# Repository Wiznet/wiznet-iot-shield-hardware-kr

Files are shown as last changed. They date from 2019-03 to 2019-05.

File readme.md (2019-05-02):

# WIZnet IoT Shield Hardware Materials

이 저장소에는 다음 자료들이 포함되어 있습니다.
* WIZnet IoT Shield 및 Cat.M1 인터페이스 보드의 하드웨어 개발 자료
  * `Schematic`, `Gerber`, `BOM` 
  * `Pinout`, `Layout` 
* WIZnet IoT Shield 하드웨어 설정 가이드

## WIZnet IoT Shield Hardware
WIZnet IoT Shield Hardware Materials 저장소에서는 WIZnet IoT Shield의 하드웨어 설정, 보드 개발 자료 및 각종 설계 가이드 문서를 저장하고 공개합니다. 이와 더불어, 제품 활용에 필요한 각종 자료와 프로그램 등도 함께 제공합니다.

**모든 개발 자료는 공개되어 있으며, 자유롭게 활용 하실 수 있습니다.**

## Folder Structure

### /docs
다양한 인터페이스 보드를 지원하는 WIZnet IoT Shield의 모듈 별 점퍼 설정 등 다양한 하드웨어 관련 문서가 위치합니다.
* imgs: 문서에서 활용된 이미지들이 저장된 폴더입니다.

### /hardware
WIZnet IoT Shield 및 인터페이스 보드의 `Schematic`, `Gerber`, `BOM`, `Layout`, `Pinout` 등의 하드웨어 개발 자료입니다. IoT Shield 및 각 Cat.M1 모듈 벤더 별 인터페이스 보드가 각각의 폴더로 나뉘어 있으며, 하드웨어 리비전 별로 관리됩니다.
* WIoT-Shield01_Vxxx: WIZnet IoT Shield 보드의 하드웨어 개발 자료
* WIoT-QC01_Vxxx: 앰투앰넷 BG96(Quectel) 모듈 인터페이스 보드의 하드웨어 개발 자료
* WIoT-WM01_Vxxx: 우리넷 WM-N400MSE 모듈 인터페이스 보드의 하드웨어 개발 자료
* WIoT-AM01_Vxxx: AM텔레콤 AMM5918K 모듈 인터페이스 보드의 하드웨어 개발 자료

### /resources
WIZnet IoT Shield의 활용에 필요한 각종 자료 및 프로그램, 드라이버 등이 위치합니다.

### /settings
Cat.M1 모듈 종류에 따른 WIZnet IoT Shield 하드웨어 설정 정보가 위치합니다.

## Examples of content

### WIZnet IoT Shield Hardware
#### Pinout
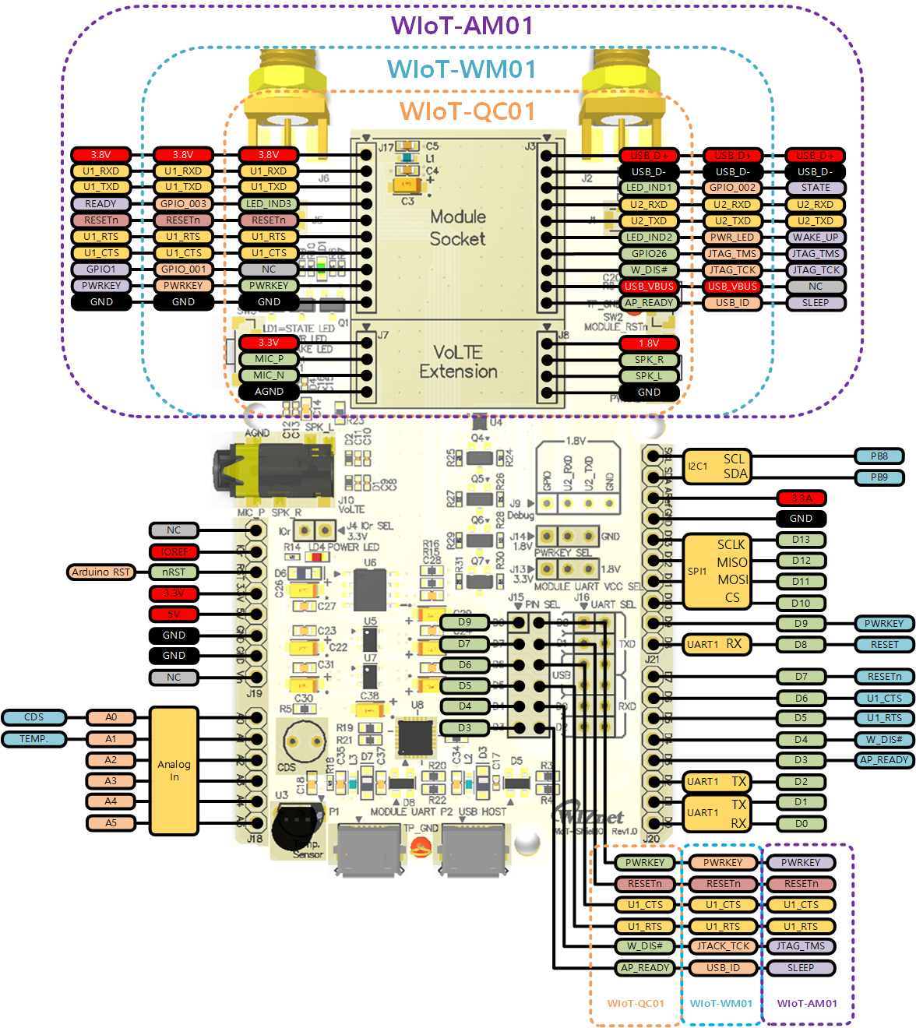
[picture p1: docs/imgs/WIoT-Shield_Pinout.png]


#### Layout
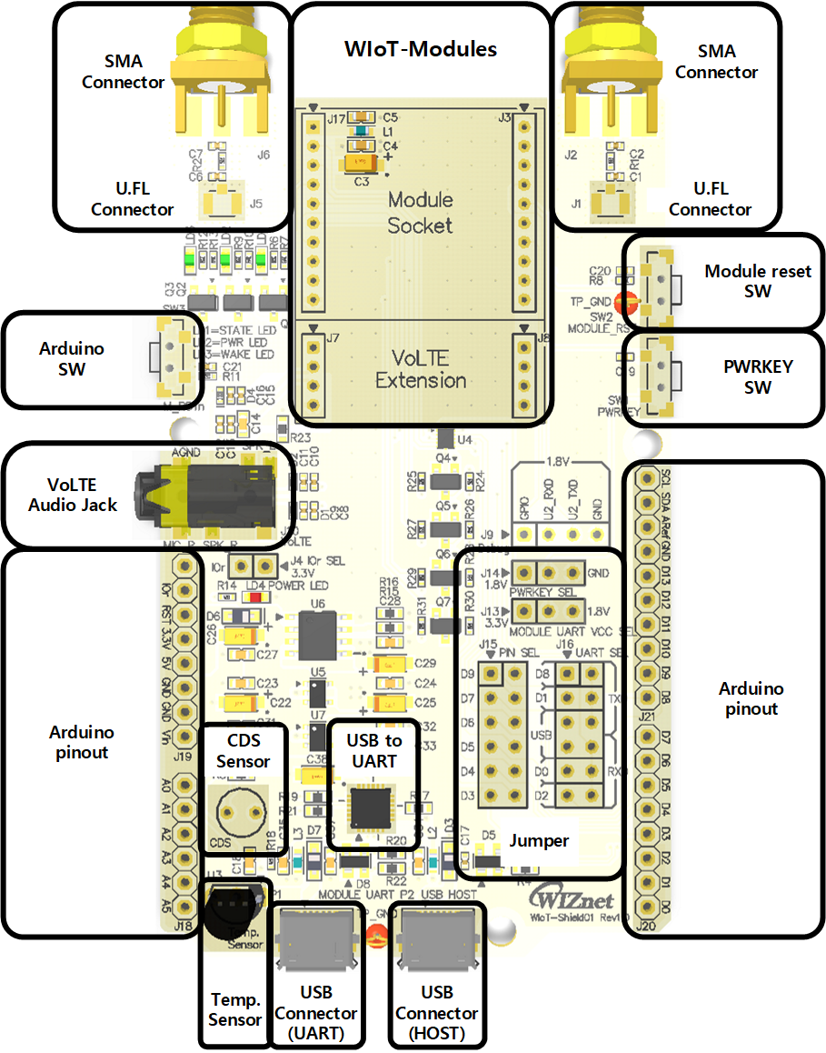
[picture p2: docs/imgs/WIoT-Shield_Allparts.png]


## Other WIZnet IoT Shield Repository
**[wiznet-iot-shield][link-wiznet-iot-shield-kr]** 저장소를 방문하면 다른 플랫폼 보드를 기반으로 동작하는 다양한 예제에 대한 저장소 리스트를 확인 할 수 있습니다.

## Support

[WIZnet Developer Forum](https://forum.wiznet.io/c/korean-forum/oshw/)

**[WIZnet Developer Forum](https://forum.wiznet.io/c/korean-forum/oshw/)** 에서 전세계의 WIZnet 기술 전문가들에게 질문하고 의견을 전달할 수 있습니다.<br>지금 방문하세요!

## License
**WIZnet IoT Shield Hardware Materials** 저장소의 모든 문서와 예제는 [Apache License, Version 2.0](https://www.apache.org/licenses/LICENSE-2.0)으로 배포됩니다.

[forum]: ./docs/imgs/forum.jpg
[link-wiznet-forum]: https://forum.wiznet.io/
[link-wiznet-iot-shield-kr]: https://github.com/Wiznet/wiznet-iot-shield-kr/

[shield-layout]: ./docs/imgs/WIoT-Shield_Allparts.png
[shield-pinout]: ./docs/imgs/WIoT-Shield_Pinout.png

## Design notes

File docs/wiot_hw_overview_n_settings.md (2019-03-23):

# WIZnet IoT Shield Hardware Guide
## 시작하기 전에
### 대상 장치
- WIoT-Shield01 (Base 보드)
- WIoT-QC01 (Socket 타입 모듈)
- WIoT-WM01 (Socket 타입 모듈)
- WIoT-AM01 (Socket 타입 모듈)

## 소개

본 문서에서는 WIoT 제품들의 하드웨어 구성 및 설정에 대한 가이드를 제공합니다.

WIoT 시리즈 보드들은 아두이노, ARM MBED 및 상용 보드 플랫폼을 기반으로 다양한 무선 모듈 응용 개발에 활용 할 수 있는 연결형 보드 및 인터페이스 보드입니다.

다양한 인터페이스 보드가 연결되는 WIoT-Shield Base보드는 두 개의 USB PORT와 CDS, TEMP 센서, VoLTE용 오디오를 지원합니다. Xbee type Socket으로 제작된 Cat.M1 모듈들을 Base보드에 결합하여 사용하도록 구성되어 있으며, 각 모듈의 종류 및 테스트 환경에 따라 WIoT-Shield의  하드웨어 설정이 변경되어야 합니다.

본 가이드는 아래와 같은 순서로 구성되어 있습니다.
 * WIoT 시리즈 하드웨어 Overview
 * WIoT 시리즈 하드웨어 Settings
   * Standard alone mode
   * Arduino/MBED mode (SerialD0,D1)
   * Arduino/MBED mode (SerialD2,D8)

## WIoT 시리즈 모듈

### 1. WIoT-Shield01
WIoT-Shield는 Base보드로서 아두이노, Arm MBED, USB를 통해 5V 전압을 인가받아 동작하며 내부에서 3.8V, 1.8V전압을 변환하여 구동됩니다.

WIoT-Shield는 WIoT 무선 모듈의 기능 동작을 위해 Power key 세팅(HIGH/LOW), UART의 전압 세팅(3.3V/1.8V)등을 제공합니다. 또한 무선 통신을 위한 U.FL, SMA 커넥터와 VoLTE 기능이 구현되어 있습니다. 프로토타입 구현에 활용 할 수 있는 CDS(조도센서), Temp.(온도센서)가 내장되어 있어 아두이노 및 Arm MBED 플랫폼 보드와 결합하여 사용 가능합니다.

#### Features
* Arduino compatible pinout
* 3종 LTE CAT.M1 모듈 사용(Quectel,AMTelecom,Woori-net)
* Power key 세팅(HIGH/LOW)
* UART 전압 세팅(3.3V/1.8V)
* VoLTE Audio JACK 구현
* U.FL / SMA 안테나 커넥터 내장
* CDS, TEMP 센서 내장
* 모듈의 부가 기능 사용을 위해 Jumper 기능 내장
* Standard alone 동작을 위한 USB 커넥터 내장
* RNDIS기능을 위한 USB 커넥터 내장





### 2. WIoT-QC01
WIoT-QC01보드는 앰투앰넷 BG96(Quectel) 모듈로 개발된 LTE Cat.M1 무선 모듈입니다.
무선 통신 시스템과 VoLTE기능을 사용할 수 있으며 Micro-SIM과 e-SIM중 한 가지를 제공합니다.

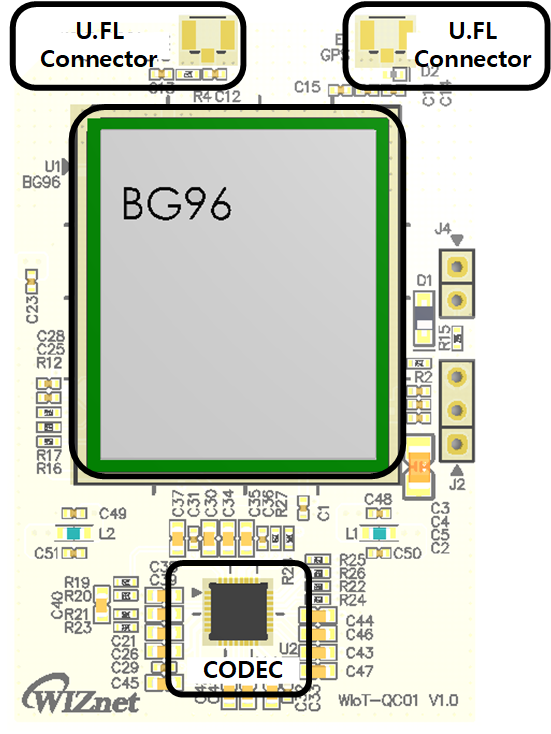
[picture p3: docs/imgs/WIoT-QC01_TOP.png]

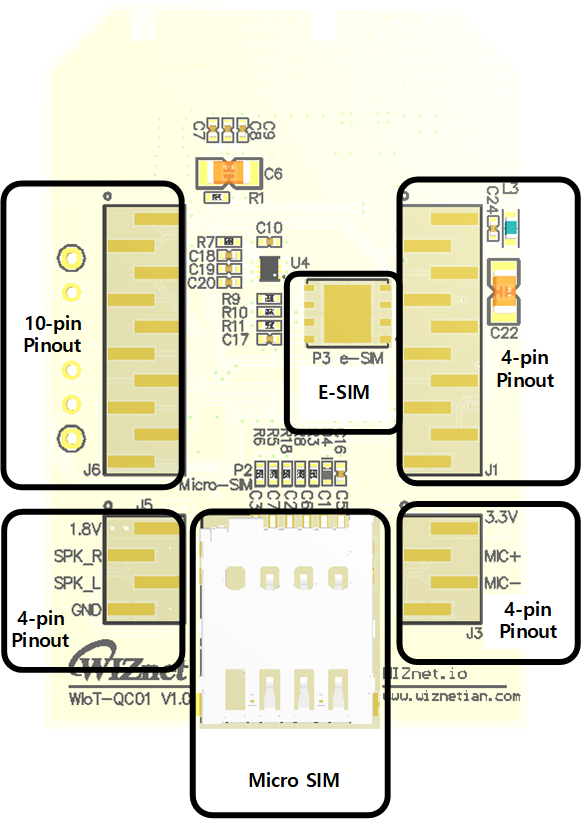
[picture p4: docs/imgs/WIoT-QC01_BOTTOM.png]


### 3. WIoT-WM01
WIoT-WM01보드는 우리넷의 WM-N400MSE을 사용하기 위한 인터페이스 보드로서 PCIe 인터페이스와 JTAG기능을 제공합니다.
Nano-SIM과 e-SIM중 한 가지를 사용할 수 있습니다.

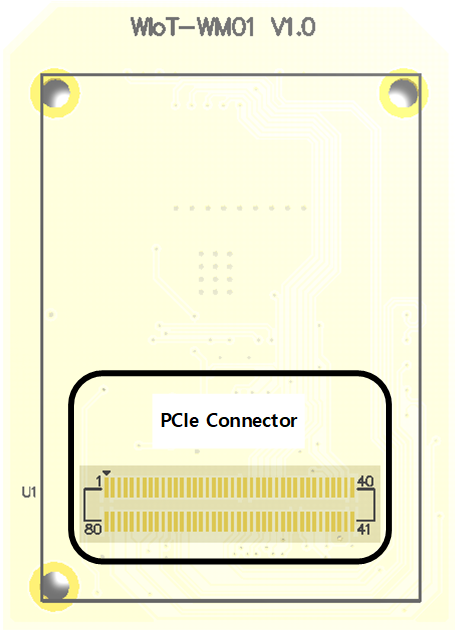
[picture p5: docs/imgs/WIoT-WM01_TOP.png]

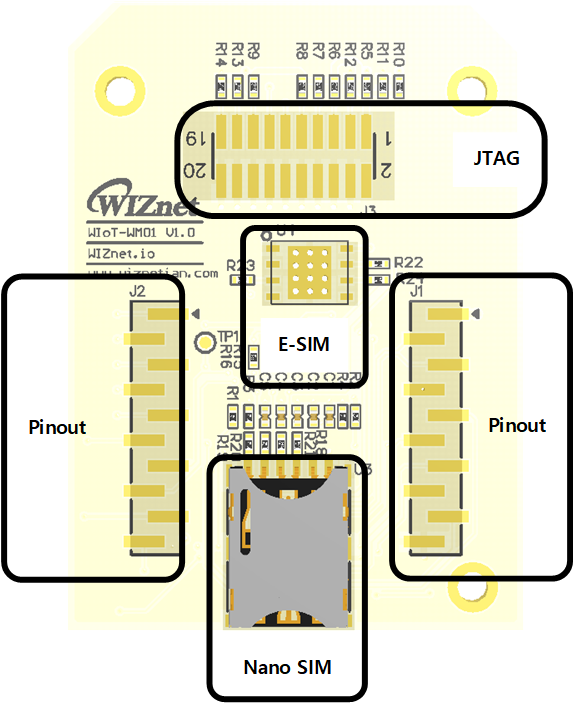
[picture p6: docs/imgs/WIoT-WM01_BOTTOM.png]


### 4. WIoT-AM01
WIoT-AM01보드는 AMTELCOM의 AMM592을 사용하기 위한 인터페이스 보드로서 PCIe 인터페이스와 JTAG기능을 제공합니다.
Micro-SIM과 e-SIM중 한 가지를 사용할 수 있습니다.

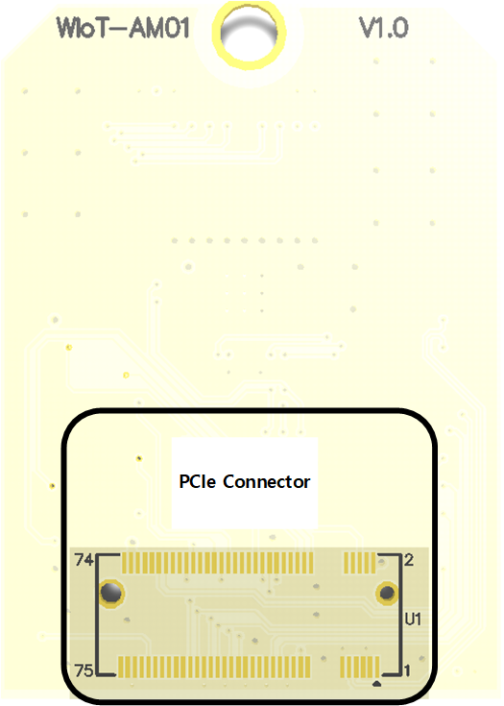
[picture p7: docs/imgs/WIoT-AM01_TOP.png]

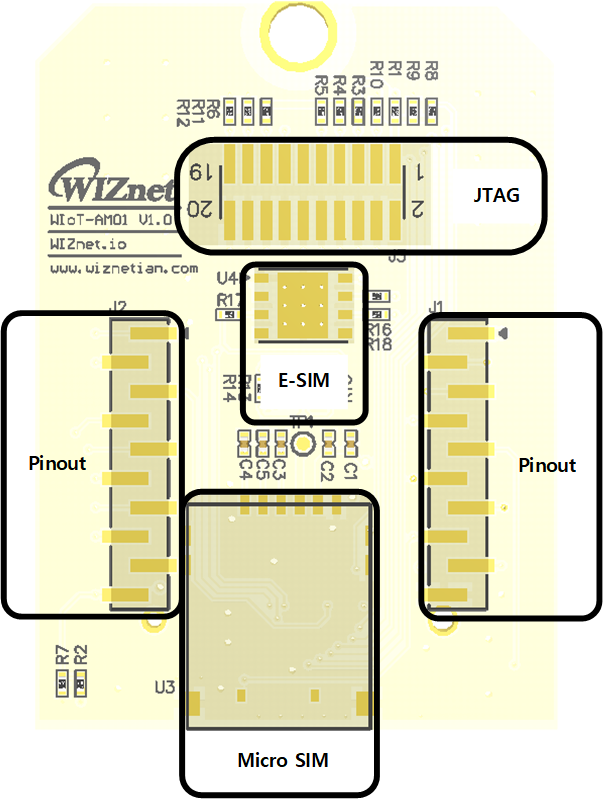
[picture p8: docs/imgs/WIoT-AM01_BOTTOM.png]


## 하드웨어 설정

### 1. WIoT 보드 기본 설정
WIoT-Shield의 기본적인 설정방법은 다음과 같습니다.

* WIoT-QC01 하드웨어 설정
  * Standard alone mode
  * Arduino / MBED mode (Serial D0,D1)
  * Arduino / MBED mode (Serial D2,D8)
* WIoT-WM01 하드웨어 설정
  * Standard alone mode
  * Arduino / MBED mode (Serial D0,D1)
  * Arduino / MBED mode (Serial D2,D8)
* WIoT-AM01 하드웨어 설정
  * Standard alone mode
  * Arduino / MBED mode (Serial D0,D1)
  * Arduino / MBED mode (Serial D2,D8)

### 2. WIoT-QC01 하드웨어 설정
* Standalone mode
  * 해당 모드는 아두이노 / MBED 등 다른 MCU기기를 결합하지 않고 WIoT-QC01를 테스트할 수 있습니다.

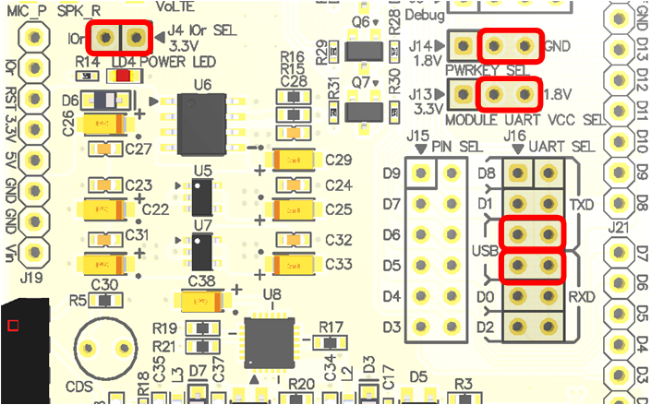
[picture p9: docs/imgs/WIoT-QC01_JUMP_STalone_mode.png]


* Arduino / MBED mode (Serial D0,D1)
  * 해당 모드는 아두이노 / MBED 등 MCU 보드의 `D0` `D1` 핀에 할당된 UART를 Cat.M1 모듈과 연결합니다.

> **Notice) 아두이노에서 코드 컴파일 및 업로드는 WIoT-Shield의 UART Jumper 제거 후 수행해야 합니다.**

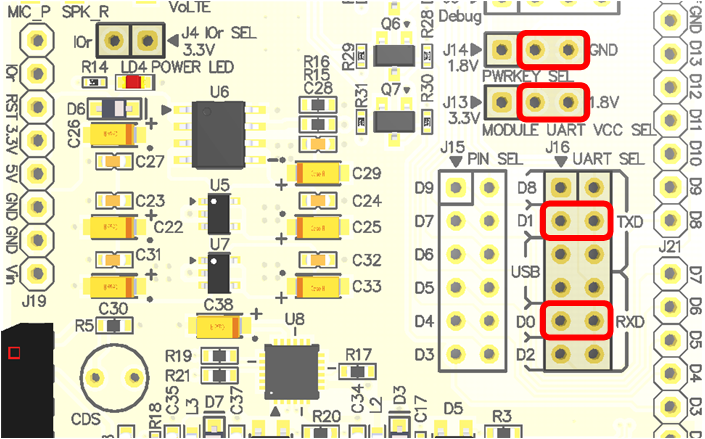
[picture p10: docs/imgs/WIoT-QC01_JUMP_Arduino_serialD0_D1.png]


* Arduino / MBED mode (Serial D2,D8)
  * 해당 모드는 아두이노 / MBED 등 MCU 보드의 `D2` `D8` 핀에 할당된 UART를 Cat.M1 모듈과 연결합니다.

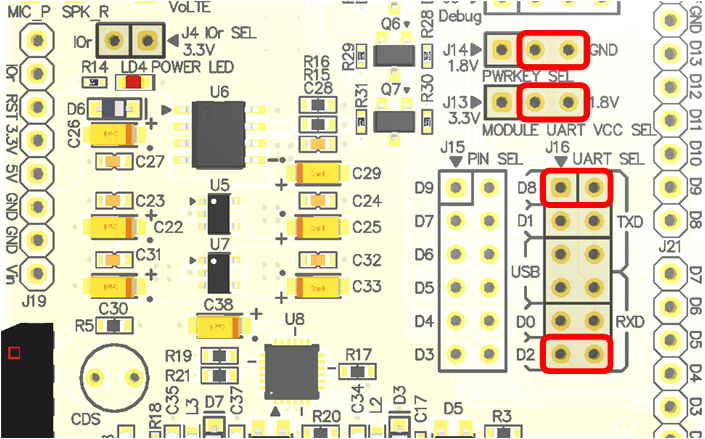
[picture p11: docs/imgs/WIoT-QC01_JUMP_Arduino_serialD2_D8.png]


### 3. WIoT-WM01 하드웨어 설정
* Standalone mode
  * 해당 모드는 아두이노 / MBED 등 다른 MCU기기를 결합하지 않고 WIoT-WM01를 테스트할 수 있습니다.

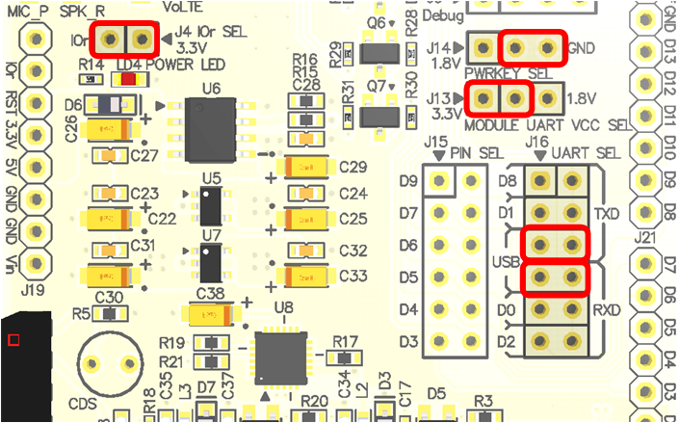
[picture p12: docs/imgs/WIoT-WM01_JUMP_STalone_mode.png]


* Arduino / MBED mode (Serial D0,D1)
  * 해당 모드는 아두이노 / MBED 등 MCU 보드의 `D0` `D1` 핀에 할당된 UART를 Cat.M1 모듈과 연결합니다.

> **Notice) 아두이노에서 코드 컴파일 및 업로드는 WIoT-Shield의 UART Jumper 제거 후 수행해야 합니다.**

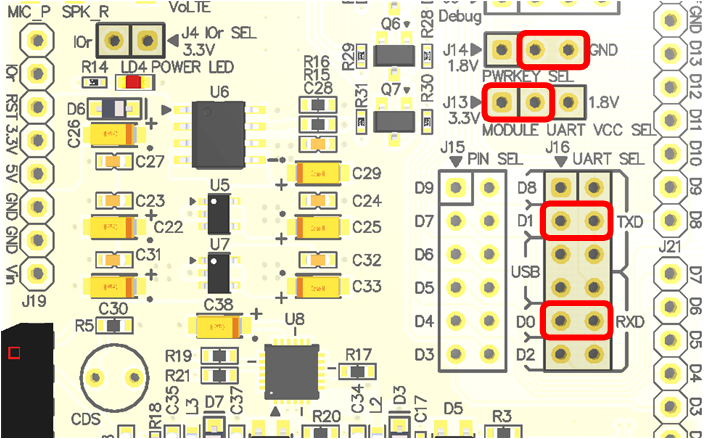
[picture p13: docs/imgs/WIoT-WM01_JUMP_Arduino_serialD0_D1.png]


* Arduino / MBED mode (Serial D2,D8)
  * 해당 모드는 아두이노 / MBED 등 MCU 보드의 `D2` `D8` 핀에 할당된 UART를 Cat.M1 모듈과 연결합니다.

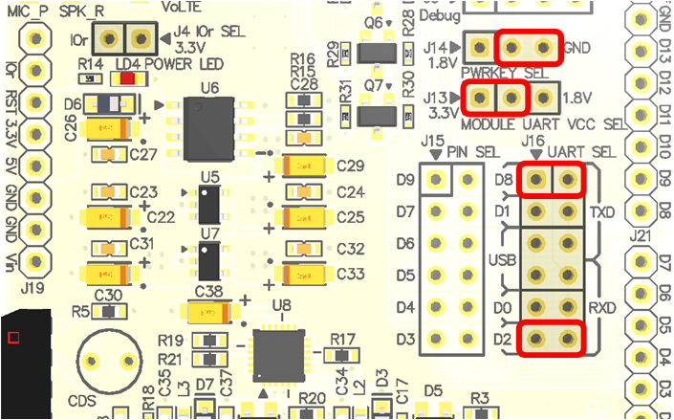
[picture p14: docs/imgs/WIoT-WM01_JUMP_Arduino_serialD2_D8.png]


### 4. WIoT-AM01 하드웨어 설정
* Standalone mode
  * 해당 모드는 아두이노/MBED 등 다른 MCU기기를 결합하지 않고 WIoT-AM01를 테스트할 수 있습니다.

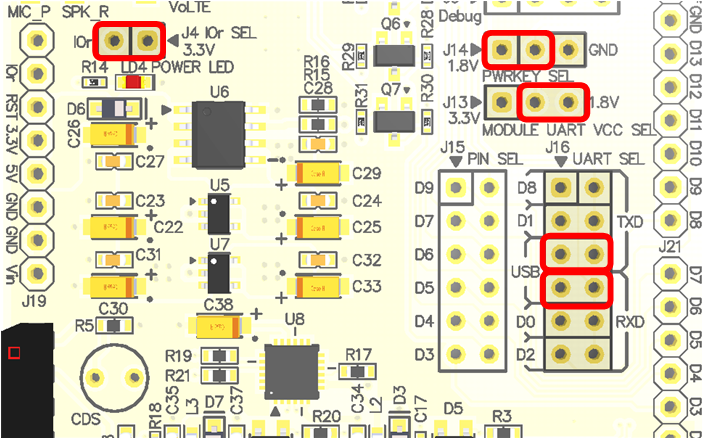
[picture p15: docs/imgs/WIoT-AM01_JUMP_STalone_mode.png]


* Arduino / MBED mode (Serial D0,D1)
  * 해당 모드는 아두이노 / MBED 등 MCU 보드의 `D0` `D1` 핀에 할당된 UART를 Cat.M1 모듈과 연결합니다.

> **Notice) 아두이노에서 코드 컴파일 및 업로드는 WIoT-Shield의 UART Jumper 제거 후 수행해야 합니다.**

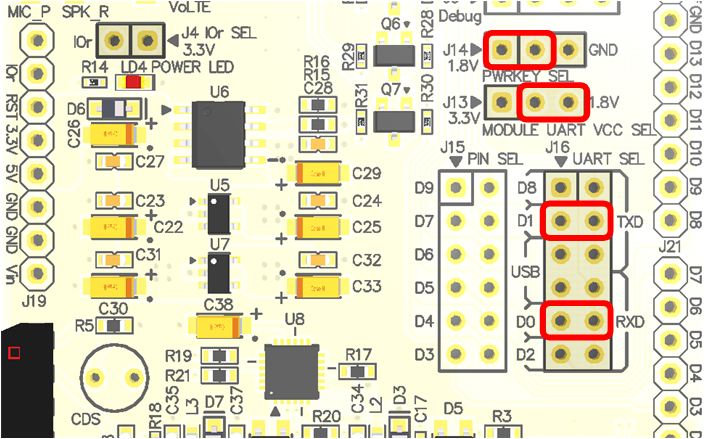
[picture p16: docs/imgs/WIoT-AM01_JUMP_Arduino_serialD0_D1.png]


* Arduino / MBED mode (Serial D2,D8)
  * 해당 모드는 아두이노 / MBED 등 MCU 보드의 `D2` `D8` 핀에 할당된 UART를 Cat.M1 모듈과 연결합니다.

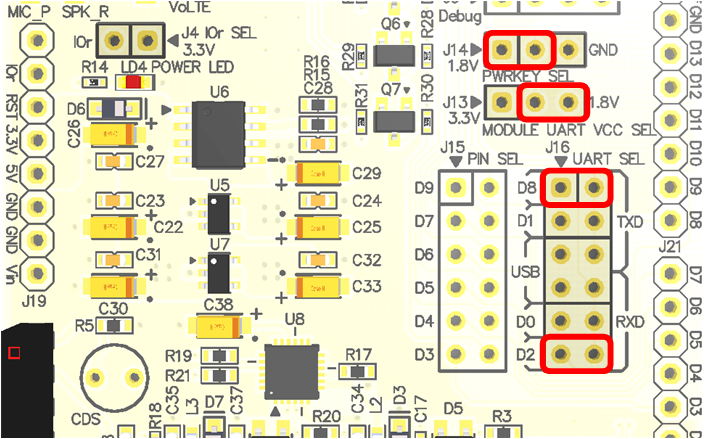
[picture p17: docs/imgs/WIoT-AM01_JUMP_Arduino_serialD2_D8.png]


[1]: ./imgs/WIoT_allparts.png
[2]: ./imgs/WIoT_series_Pinout.png
[3]: ./imgs/WIoT-AM01_TOP.png
[4]: ./imgs/WIoT-AM01_BOTTOM.png
[5]: ./imgs/WIoT-AM01_Pinout.png
[6]: ./imgs/WIoT-AM01_JUMP_STalone_mode.png
[7]: ./imgs/WIoT-AM01_JUMP_Arduino_serialD0_D1.png
[8]: ./imgs/WIoT-AM01_JUMP_Arduino_serialD2_D8.png
[9]: ./imgs/WIoT-QC01_TOP.png
[10]: ./imgs/WIoT-QC01_BOTTOM.png
[11]: ./imgs/WIoT-QC01_Pinout.png
[12]: ./imgs/WIoT-QC01_JUMP_STalone_mode.png
[13]: ./imgs/WIoT-QC01_JUMP_Arduino_serialD0_D1.png
[14]: ./imgs/WIoT-QC01_JUMP_Arduino_serialD2_D8.png
[15]: ./imgs/WIoT-WM01_TOP.png
[16]: ./imgs/WIoT-WM01_BOTTOM.png
[17]: ./imgs/WIoT-WM01_Pinout.png
[18]: ./imgs/WIoT-WM01_JUMP_STalone_mode.png
[19]: ./imgs/WIoT-WM01_JUMP_Arduino_serialD0_D1.png
[20]: ./imgs/WIoT-WM01_JUMP_Arduino_serialD2_D8.png

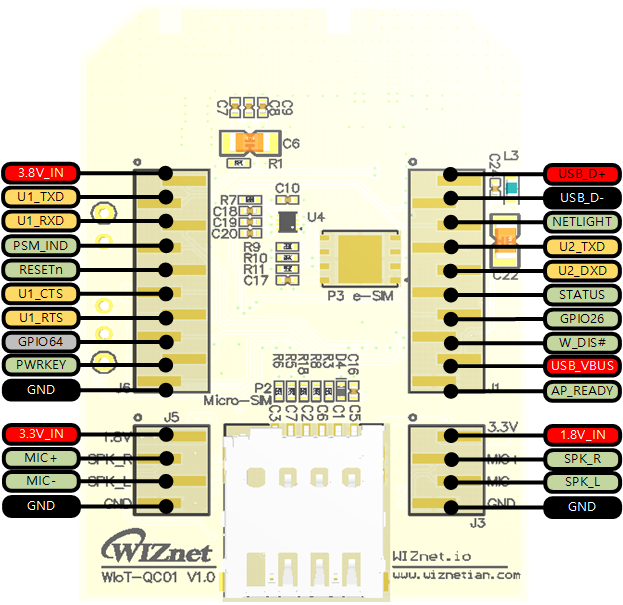
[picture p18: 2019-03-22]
docs/imgs/WIoT-QC01_Pinout.png

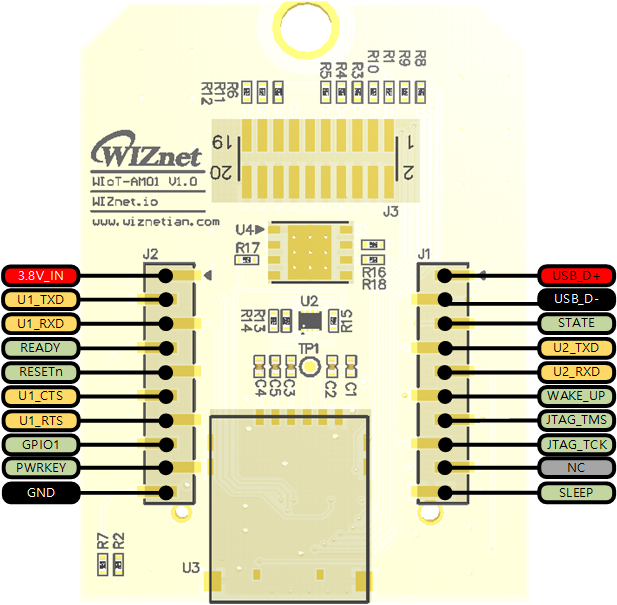
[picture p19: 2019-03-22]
docs/imgs/WIoT-AM01_Pinout.png

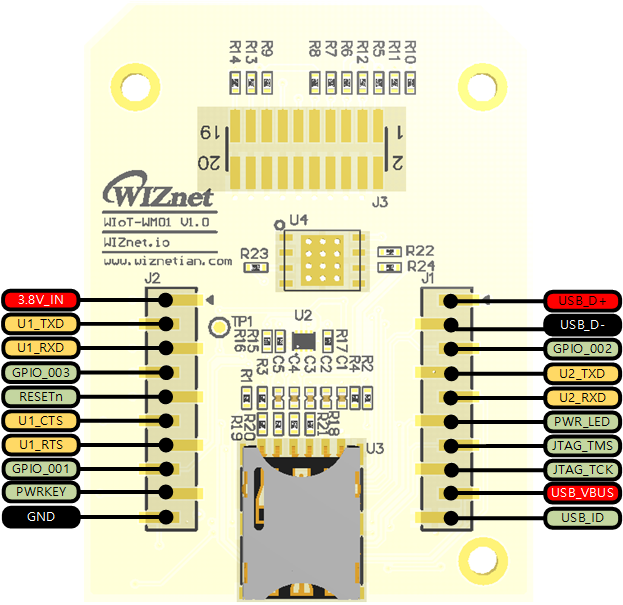
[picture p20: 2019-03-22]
docs/imgs/WIoT-WM01_Pinout.png

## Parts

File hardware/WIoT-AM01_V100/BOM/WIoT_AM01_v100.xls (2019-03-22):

WIoT-AM01 V1.0 Partlist
Item | Q.ty | Reference | Part | Tech. Characteristics | Package
1 | 1 | C1 | 1uF | 50V-5% Ceramic | CASE 0402
2 | 4 | C2,C3,C4,C5 | 33pF | 50V-5% Ceramic | CASE 0402
3 | 2 | J1,J2 | 2.00mm Pin haeder SMD 1x10 | 2.00mm Pin haeder 1x10, SMD Male | SMD
4 | 3 | R16,R17,R18 | 0R | 1/10W-5% SMD | CASE 0402
6 | 1 | U1 | 24-6411-067-101-894B | PCIe interface connector (Kyocera) | SMD
7 | 1 | U2 | TPD3F303DQDR | ESD Protection SIM | PWSON08(0.4/1.45X1.8)
8 | 1 | U3 | MOLEX-SD-78646-001 | Micro SIM SMT 1.45mm Push/Pull (Molex) | SMD
9 | 1 | J3 | 1.27mm 2x10 Pin Header SMD | Not Mount | SMD
10 | 1 | J4 | 2.54mm Pin haeder 1x2 | Not Mount | DIP
11 | 1 | U4 | e-SIM | Not Mount | SMD
12 | 4 | R1,R13,R14,R15 | 0R | Not Mount | CASE 0402
13 | 10 | R2,R3,R4,R5,R6,R7,R8,R9,R11,R12 | 10k | Not Mount | CASE 0402
14 | 1 | R10 | 47k | Not Mount | CASE 0402
15 | 1 |  | PCB | 4-Layer 50mm x 36mm

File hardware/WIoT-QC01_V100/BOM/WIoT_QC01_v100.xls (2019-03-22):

WIoT-QC01 V1.0 Partlist
Item | Q.ty | Reference | Part | Tech. Characteristics | Package
1 | 17 | C1,C3,C7,C10,C16,C23,C24,C25,C28,C29,C31,C33,C36,C48,C49,C50,C51 | 0.1uF | 50V-5% Ceramic | CASE 0402
2 | 2 | C43,C44 | 1uF | 25V-5% Ceramic | CASE 0603
3 | 8 | C34,C35,C38,C39,C41,C42,C46,C47 | 2.2uF | 25V-5% Ceramic | CASE 0603
4 | 6 | C21,C26,C30,C32,C37,C45 | 4.7uF | 25V-5% Ceramic | CASE 0603
5 | 1 | C22 | 4.7uF/16V | Tantal CAP, A Size, 4.7uF/16V, +/-20% | EIA/IECQ 3216
6 | 1 | C40 | 10uF | 25V-5% Ceramic | CASE 0603
7 | 2 | C2,C6 | 10uF/16V | Tantal CAP, A Size, 10uF/16V, +/-20% | EIA/IECQ 3216
8 | 2 | C5,C9 | 10pF | 25V-5% Ceramic | CASE 0402
9 | 5 | C4,C8,C18,C19,C20 | 33pF | 25V-5% Ceramic | CASE 0402
10 | 1 | C11 | 100pF | 25V-5% Ceramic | CASE 0402
11 | 2 | J1,J6 | 2.00mm Pin haeder SMD 1x10 | 2.00mm Pin haeder 1x10, SMD Male | SMD
12 | 2 | J3,J5 | 2.00mm Pin haeder SMD 1x4 | 2.00mm Pin haeder 1x4, SMD Male | SMD
13 | 1 | P2 | MOLEX-SD-78646-001 | Micro SIM SMT 1.45mm Push/Pull (Molex) | SMD
14 | 2 | E1,E2 | 20279-001E-03 | U.FL Connector | SMD
15 | 2 | L1,L2,L3 | HH-1M1608-121JT | Bead for Power Line, 120[ohm] | CASE 0603
16 |  | D1 | PZ3D4V2H | Zener 5.1V | SOD-323
17 | 1 | D2 | LXES15AAA1-133 | Bi-directional TVS diode | D0402
18 | 1 | D4 | ESD9X5.0ST5G | Uni-directional TVS diode | SOD-923(1-C,2-A)
19 | 11 | R1,R2,R4,R5,R6,R8,R18,R22,R24,R25,R26 | 0R | 1/10W-5% SMD | CASE 0402
20 | 2 | R19,R23 | 1k | 1/10W-5% SMD | CASE 0402
21 | 2 | R20,R21 | 1.5k | 1/10W-5% SMD | CASE 0402
22 | 6 | R12,R15,R16,R17,R27,R28 | 4.7K | 1/10W-5% SMD | CASE 0402
23 | 1 | R7 | 15k | 1/10W-5% SMD | CASE 0402
24 | 1 | R3 | 51k | 1/10W-5% SMD | CASE 0402
25 | 1 | U1 | BG96 | Quectel, BG96, LTE CAT M1 module, | BG-96
26 | 1 | U2 | ALC5616 | AUDIO CODEC with QUECTEL VOLTE (Realtek) | QFN32(0.4/4.0)
27 | 1 | U4 | TPD3F303DQDR | ESD Protection SIM | PWSON08(0.4/1.45X1.8)
28 | 5 | C12,C13,C14,C15,C17 | 0.1uF | Not Mount | CASE 0402
29 | 1 | J2 | 2.54mm Pin haeder 1x3 | Not Mount | DIP
30 | 1 | J4 | 2.54mm Pin haeder 1x2 | Not Mount | DIP
31 | 1 | P3 | e-SIM | Not Mount | SMD
32 | 3 | R9,R10,R11 | 0R | Not Mount | CASE 0402
33 | 1 |  | PCB | 4-Layer 54mm x 36mm

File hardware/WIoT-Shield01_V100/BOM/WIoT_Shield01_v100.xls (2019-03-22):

WIoT-Shield01 V1.0 Partlist
Item | Q.ty | Reference | Part | Tech. Characteristics | Package
1 | 4 | C17,C19,C20,C21 | 0.1uF | 50V-5% Ceramic | CASE 0402
2 | 12 | C4,C5,C18,C23,C24,C27,C28,C31,C32,C34,C35,C37 | 0.1uF | 50V-5% Ceramic | CASE 0603
3 | 1 | C14 | 4.7uF | 50V-5% Ceramic | CASE 0603
4 | 6 | C3,C22,C25,C30,C33,C38 | 4.7uF/16V | Tantal CAP, A Size, 4.7uF/16V, +/-20% | EIA/IECQ 3216
5 | 2 | C26,C29 | 10uF/16V | Tantal CAP, A Size, 10uF/16V, +/-20% | EIA/IECQ 3216
6 | 4 | C8,C10,C12,C15 | 10pF | 25V-5% Ceramic | CASE 0402
7 | 4 | C9,C11,C13,C16 | 33pF | 25V-5% Ceramic | CASE 0402
8 | 2 | J1,J5 | 20279-001E-03 | U.FL CONNECTOR | SMD
9 | 2 | J2,J6 | SMA_Female SMA-4-4R 1.6T | SMA_Female | SMD
10 | 2 | J3,J17 | 2.00mm 1x10 Pin Header Socket | 2.00mm 1x10 Pin Header Socket DIP | DIP
11 | 1 | J4 | 2.54mm 1x2 Pin Header DIP | 2.54mm 1x2 Pin Header DIP | DIP
12 | 2 | J7, J8 | 2.00mm 1x4 Pin Header DIP | 2.00mm 1x4 Pin Header Socket DIP | DIP
13 | 2 | J13,J14 | 2.54mm 1x3 Pin Header DIP | 2.54mm 1x3 Pin Header DIP | DIP
14 | 2 | J15,J16 | 2.54mm 2x6 Pin Header DIP | 2.54mm 2x6 Pin Header DIP | DIP
15 | 1 | J18 | 2702747 | ARDUINO 2.54mm 1x6 Pin Header Socket DIP | DIP
16 | 2 | J19,J20 | 2702747 | ARDUINO 2.54mm 1x8 Pin Header Socket DIP | DIP
17 | 1 | J21 | 2702747 | ARDUINO 2.54mm 1x10 Pin Header Socket DIP | DIP
18 | 2 | P1,P2 | 47346-0001 | USB-MOLEX-47346 | MICRO USB B Type
19 | 1 | J10 | gec-3896D | Phonejack 6pin | SMD
20 | 3 | SW1,SW2,SW3 | NW3-A06-B5 | Angle TACT SW, SMD | SMD
21 | 3 | L1,L2,L3 | HH-1M1608-121JT | Bead for Power Line, 120[ohm] | CASE 0603
22 | 2 | D1,D2 | ESD9B5.0ST5G | Bi-directional TVS diode | SOD-882(TVS)
23 | 3 | D3,D6,D7 | BAT60A | Silicon Schottky Diode | SOD-323(1-C,2-A)
24 | 1 | D4 | ESD9X5.0ST5G | Uni-directional TVS diode | SOD-923(1-C,2-A)
25 | 2 | D5, D8 | PRTR5V0U2X | Ultra low capacitance double rail-to-rail ESD protection diode | SOT-143
26 | 4 | LD1,LD2,LD3 | Green LED | CHIP-LED, Red | CASE 0603
27 | 1 | LD4 | Red LED | CHIP-LED, Red | CASE 0603
28 | 3 | R1,R2,R18 | 0R | 1/10W-5% SMD | CASE 0402
29 | 3 | R19,R21,R23 | 0R | 1/10W-5% SMD | CASE 0603
30 | 4 | 'R3,R4,R20,R22 | 33R | 1/10W-5% SMD | CASE 0603
31 | 7 | R6,R7,R9,R10,R12,R13,R14 | 1k | 1/10W-5% SMD | CASE 0402
32 | 8 | R24,R25,R26,R27,R28,R29,R30,R31 | 4.7K | 1/10W-5% SMD | CASE 0402
33 | 1 | R17 | 4.7k | 1/10W-5% SMD | CASE 0603
34 | 1 | R5 | 10k | 1/10W-1% SMD | CASE 0603
35 | 1 | R16 | 30.1k | 1/10W-5% SMD | CASE 0603
36 | 1 | R15 | 200k | 1/10W-5% SMD | CASE 0603
37 | 1 | CDS | GL5537 | 10k, Photoresistor | DIP
38 | 1 | U3 | LM35 | Temperature Sensor | TO-92
39 | 1 | U4 | NLSX5014MUTAG | Level-Shifter | UQFN12(0.4/1.7X2)
40 | 1 | U5 | AP7365-33WG-7 | 3.3V 600mA Regulator/SOT25(Fixed Output) | SOT-25
41 | 1 | U6 | TPS7A7002DDAR | TPS7A7002DDAR | SO-08-EP
42 | 1 | U7 | AP7365-18WG-7 | 3.3V 600mA Regulator/SOT25(Fixed Output) | SOT-25
43 | 1 | U8 | CP2104-GM | USB to UART Bridge, SiliconLabs | QFN24(0.5/4X4)
44 | 3 | Q1,Q2,Q3 | Q-MMBT4401 | NPN General-Purpose Amplifier | SOT-23-3L
45 | 4 | Q4,Q5,Q6,Q7 | Q-2N7002 | N-Channel 60-V (D-S) MOSFET | SOT-23-3L
46 | 4 | C1,C2,C6,C7 | 0.1uF | Not Mount | CASE 0402
47 | 1 | J9 | 2.54mm Pin haeder 1x4 | Not Mount | DIP
48 | 2 | R8,R11 | 0R | Not Mount | CASE0402
49 | 1 |  | PCB | 4-Layer 90mm x 53.315mm

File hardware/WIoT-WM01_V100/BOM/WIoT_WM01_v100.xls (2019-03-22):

WIoT-WM01 V1.0 Partlist
Item | Q.ty | Reference | Part | Tech. Characteristics | Package
1 | 2 | C1 | 1uF | 50V-5% Ceramic | CASE 0402
2 | 5 | C2,C3,C4,C5 | 33pF | 50V-5% Ceramic | CASE 0402
3 | 2 | J1,J2 | 2.00mm Pin haeder SMD 1x10 | 2.00mm Pin haeder 1x10, SMD Male | SMD
5 | 6 | R15,R16,R17,R19,R20,R21 | 0R | 1/10W-5% SMD | CASE 0402
6 | 1 | U1 | AXK6F80347YG | PCIe interface connector (Panasonic Industrial Devices) | SMD
7 | 1 | U3 | 693-043-020-611 | Nano SIM SMT 1.2mm Push/Pull (Wurth Electronics) | 693-043-020-611
8 | 5 | U2 | TPD3F303DQDR | Not Mount | PWSON08(0.4/1.45X1.8)
9 |  | U4 | e-SIM | Not Mount | SMD
10 | 1 | J3 | 1.27mm 2x10 Pin Header SMD | Not Mount | SMD
11 | 4 | R18,R22,R23,R24 | 0R | Not Mount | CASE 0402
12 | 13 | R1,R2,R3,R4,R5,R6,R7,R8,R9,R10,R11,R13,R14 | 10k | Not Mount | CASE 0402
13 | 1 | R12 | 47K | Not Mount | CASE 0402
14 | 1 |  | PCB | 4-Layer 50mm x 36mm

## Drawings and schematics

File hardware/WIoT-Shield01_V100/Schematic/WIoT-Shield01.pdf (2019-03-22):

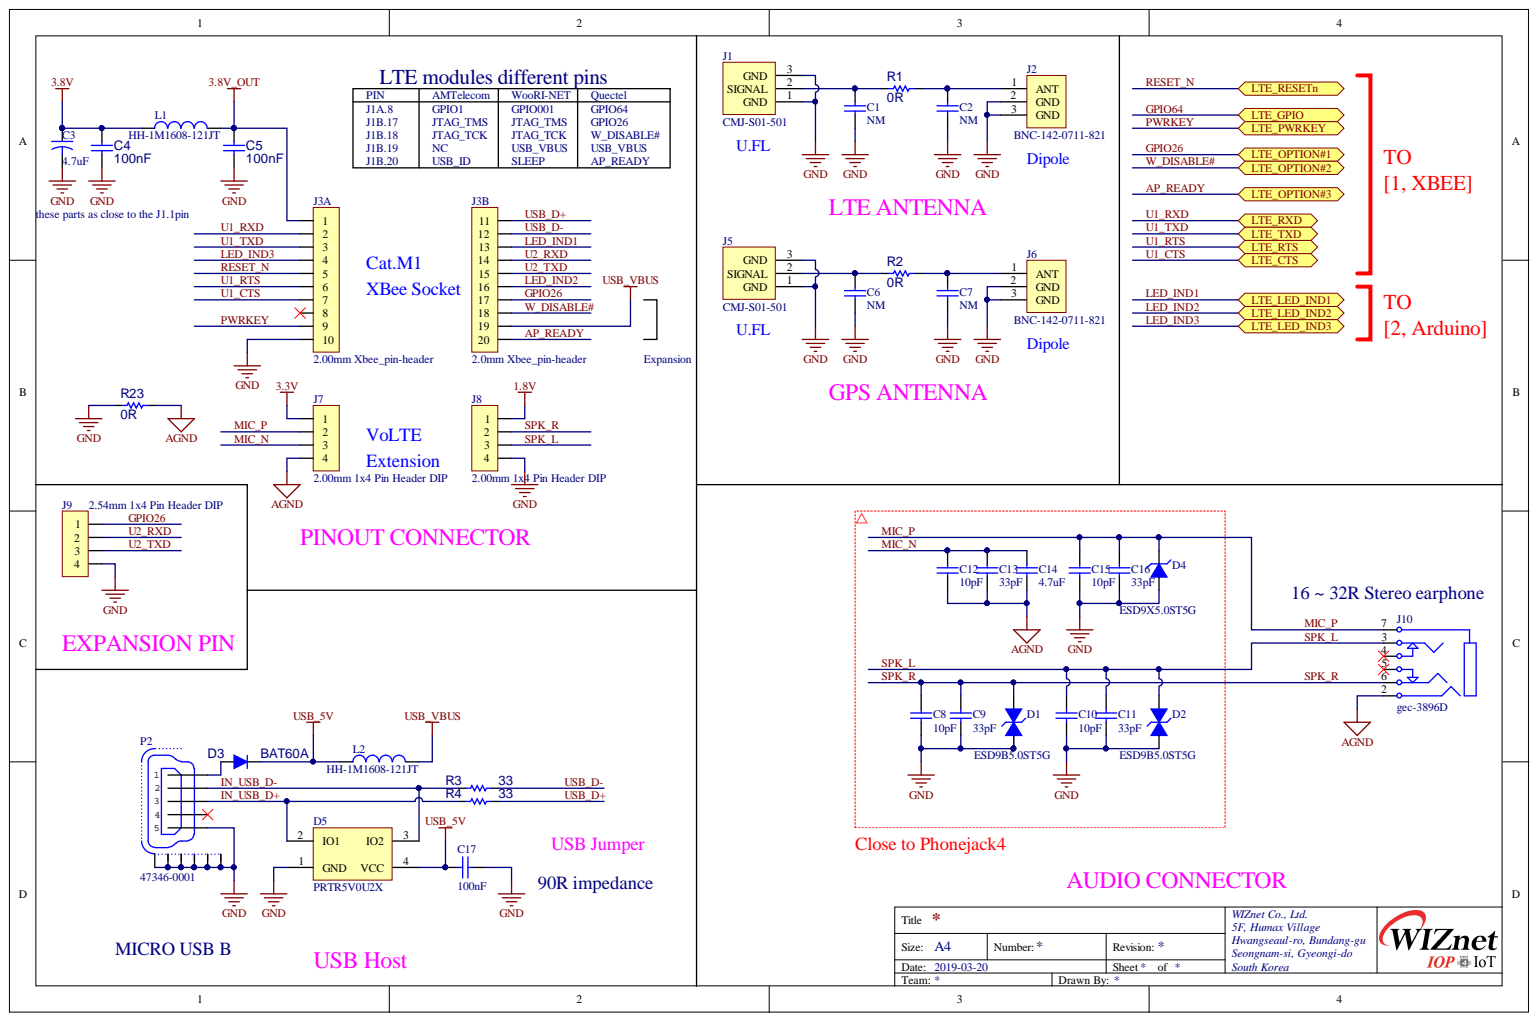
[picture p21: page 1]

LTE modules different pins

these parts as close to the J1.1pin

GND 2

W_DISABLE#

* Title | WIZnet Co., Ltd. 5F, Humax Village Hwangseaul-ro, Bundang-gu Seongnam-si, Gyeongi-do South Korea

A4 Size: | * Number: | * Revision:

Date: 2019-03-20 | | Sheet * of *
Team: * | Drawn By: *

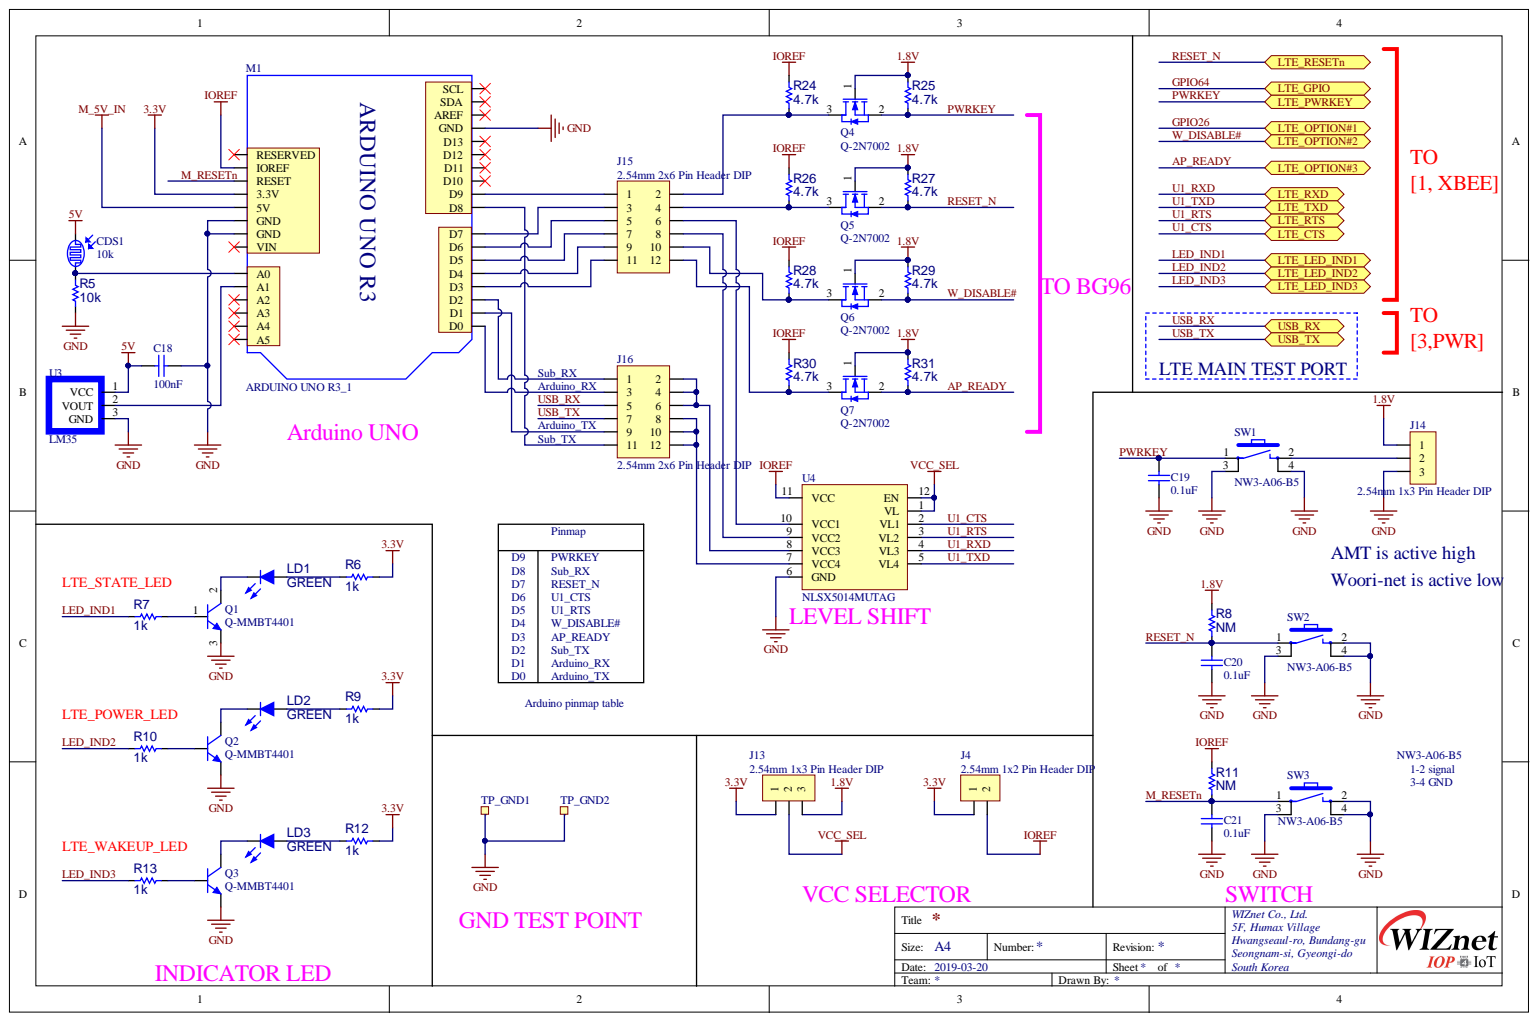
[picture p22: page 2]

GND AREF SDA SCL

RESERVED IOREF RESET 3.3V 5VGND GND
RESETn GND

* Titl e | WIZn et Co. , Ltd. 5 F, Humax Vi l l a g e Hwan gseau l-r o , Bunda ng-g u S e ong nam-s i , Gy eon g i-do Sou th Kore a

A4 * S ize : | * Drawn Nu mb er: | * R e vi s ion :

Da t e : | | S h e e t o f
Te a m : | By:

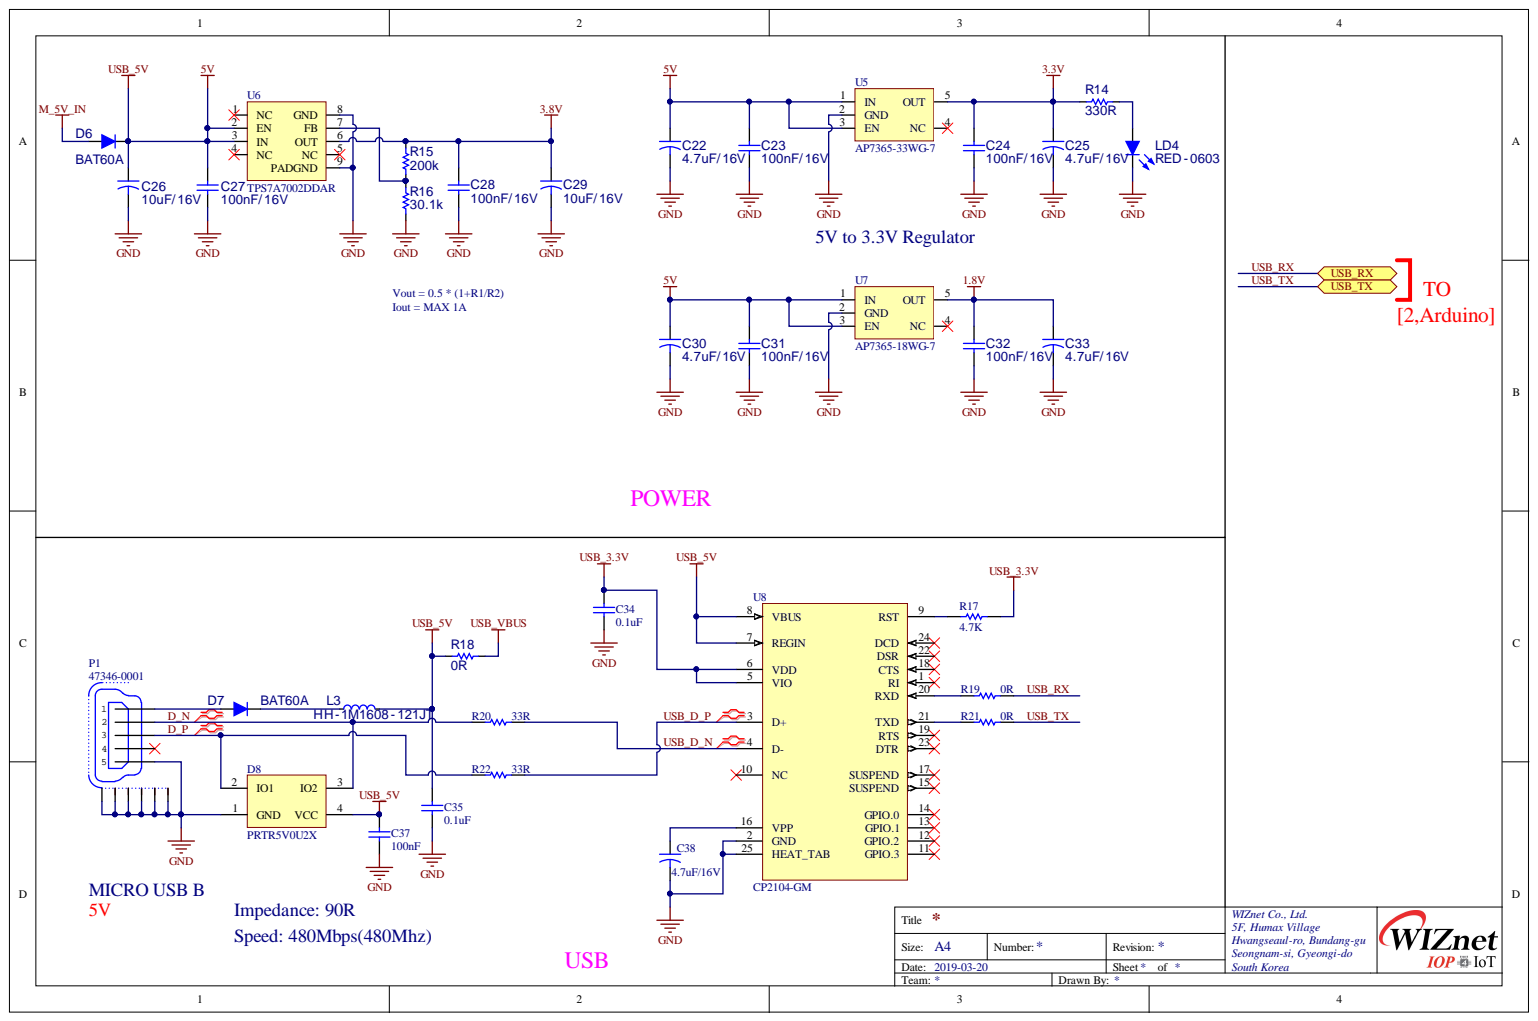
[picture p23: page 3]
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

A4 Size: | * Number: | * Revision:

Date: | | Sheet of *
Team: * | Drawn By: *

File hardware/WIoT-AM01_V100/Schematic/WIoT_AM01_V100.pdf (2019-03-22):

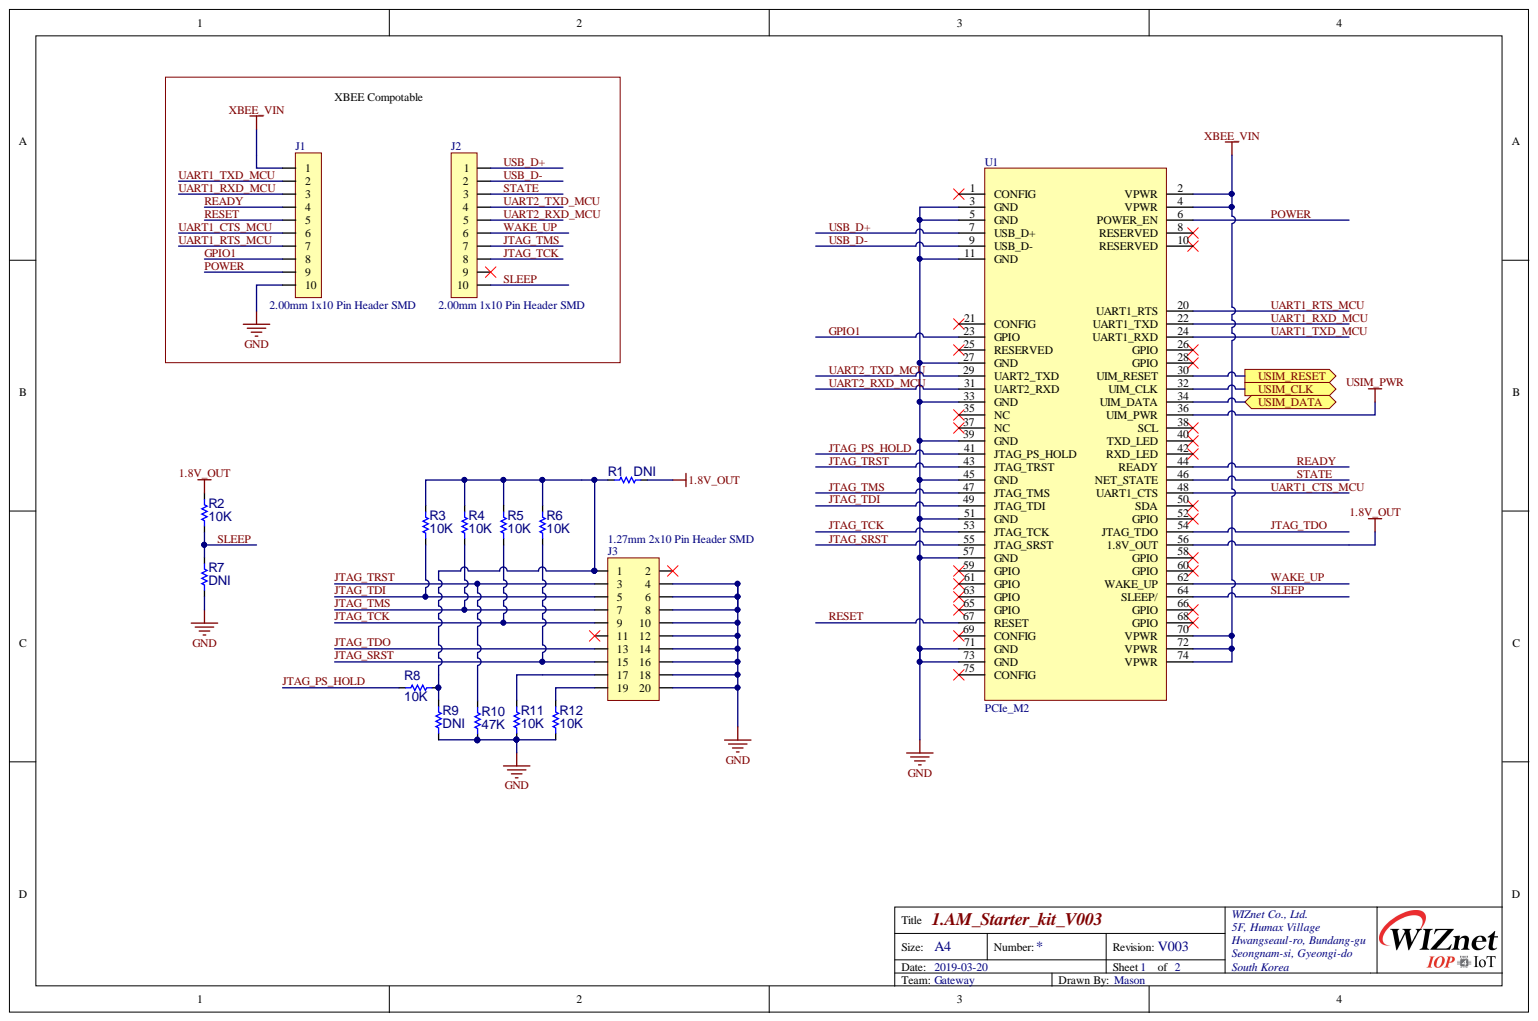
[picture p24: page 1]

3 1 | 3 2
3 3 | 3 4
3 5 | 3 6

4 1 | 4 2
4 3 | 4 4
4 5 | 4 6

5 1 | 5 2
5 3 | 5 4
5 5 | 5 6

1.A M_Starte Titl e | WIZn et Co. , Ltd. 5 F, Humax Vi l l a g e Hwan gseau l-r o , Bunda ng-g u S e ong nam-s i , Gy eon g i-do Sou th Kore a

A4 Gatewa S ize : | Nu mb er: | R e vi s ion :

Da t e : 201 9-03-20 | | S h e e t 1 o f 2
Te a m : y | Drawn By: Maso n

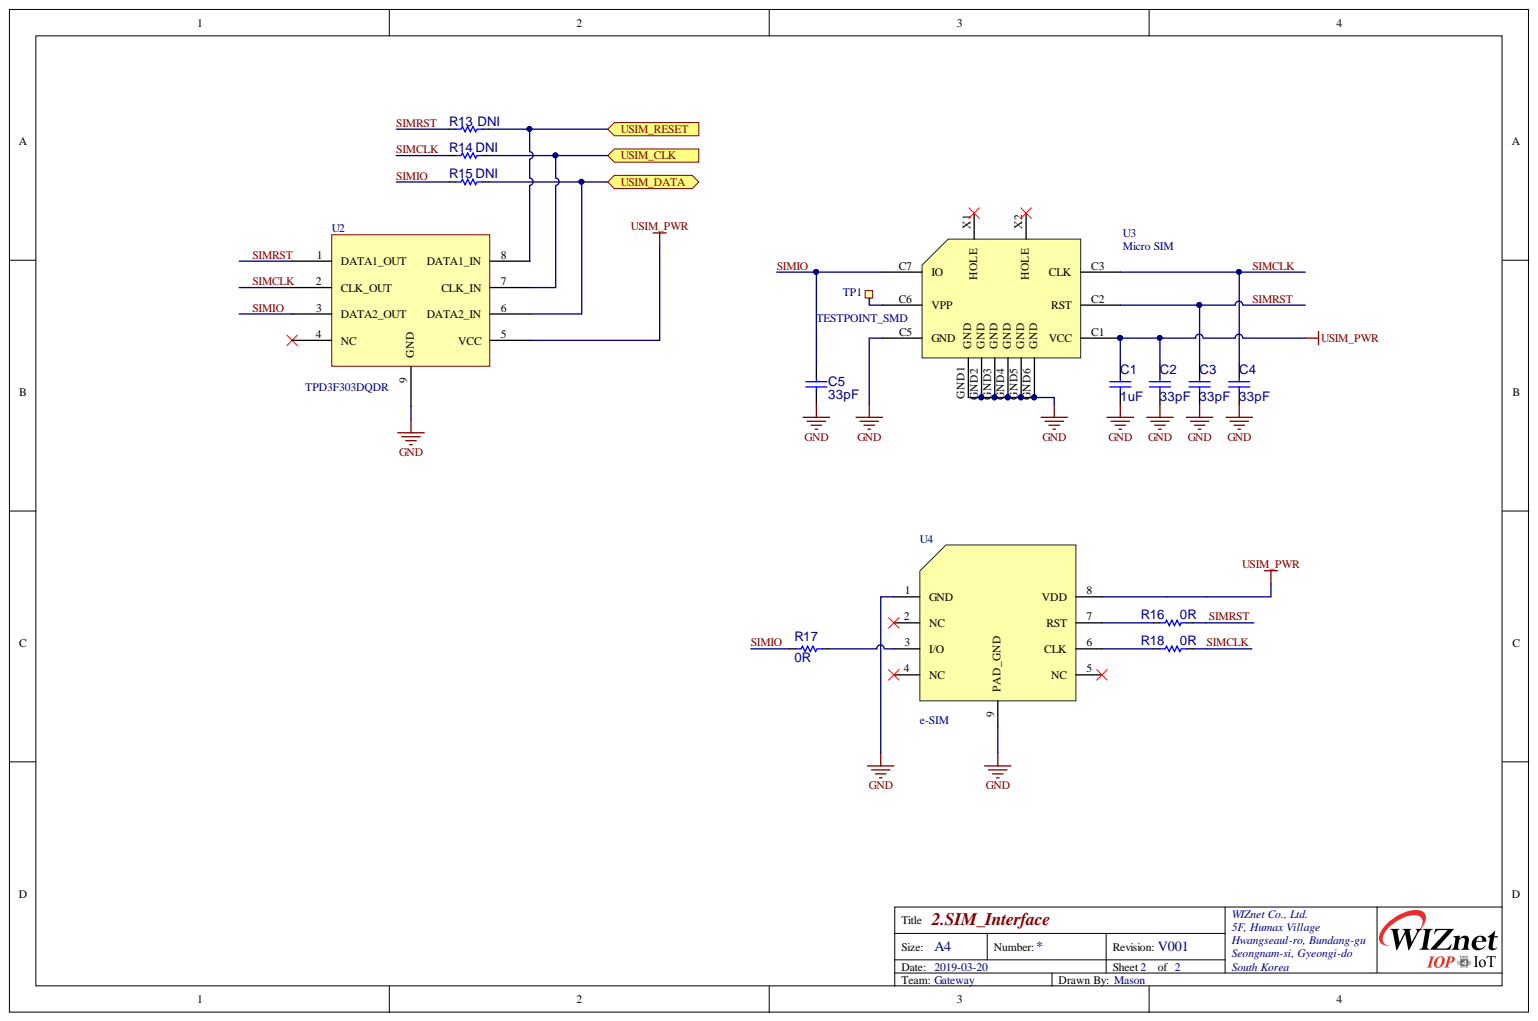
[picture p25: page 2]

2.SIM_Interface Title | WIZnet Co., Ltd. 5F, Humax Village Hwangseaul-ro, Bundang-gu Seongnam-si, Gyeongi-do South Korea

A4 Size: | * Number: | V001 Revision:

Date: 2019-03-20 | | Sheet 2 of 2
Team: Gateway | Drawn By: Mason

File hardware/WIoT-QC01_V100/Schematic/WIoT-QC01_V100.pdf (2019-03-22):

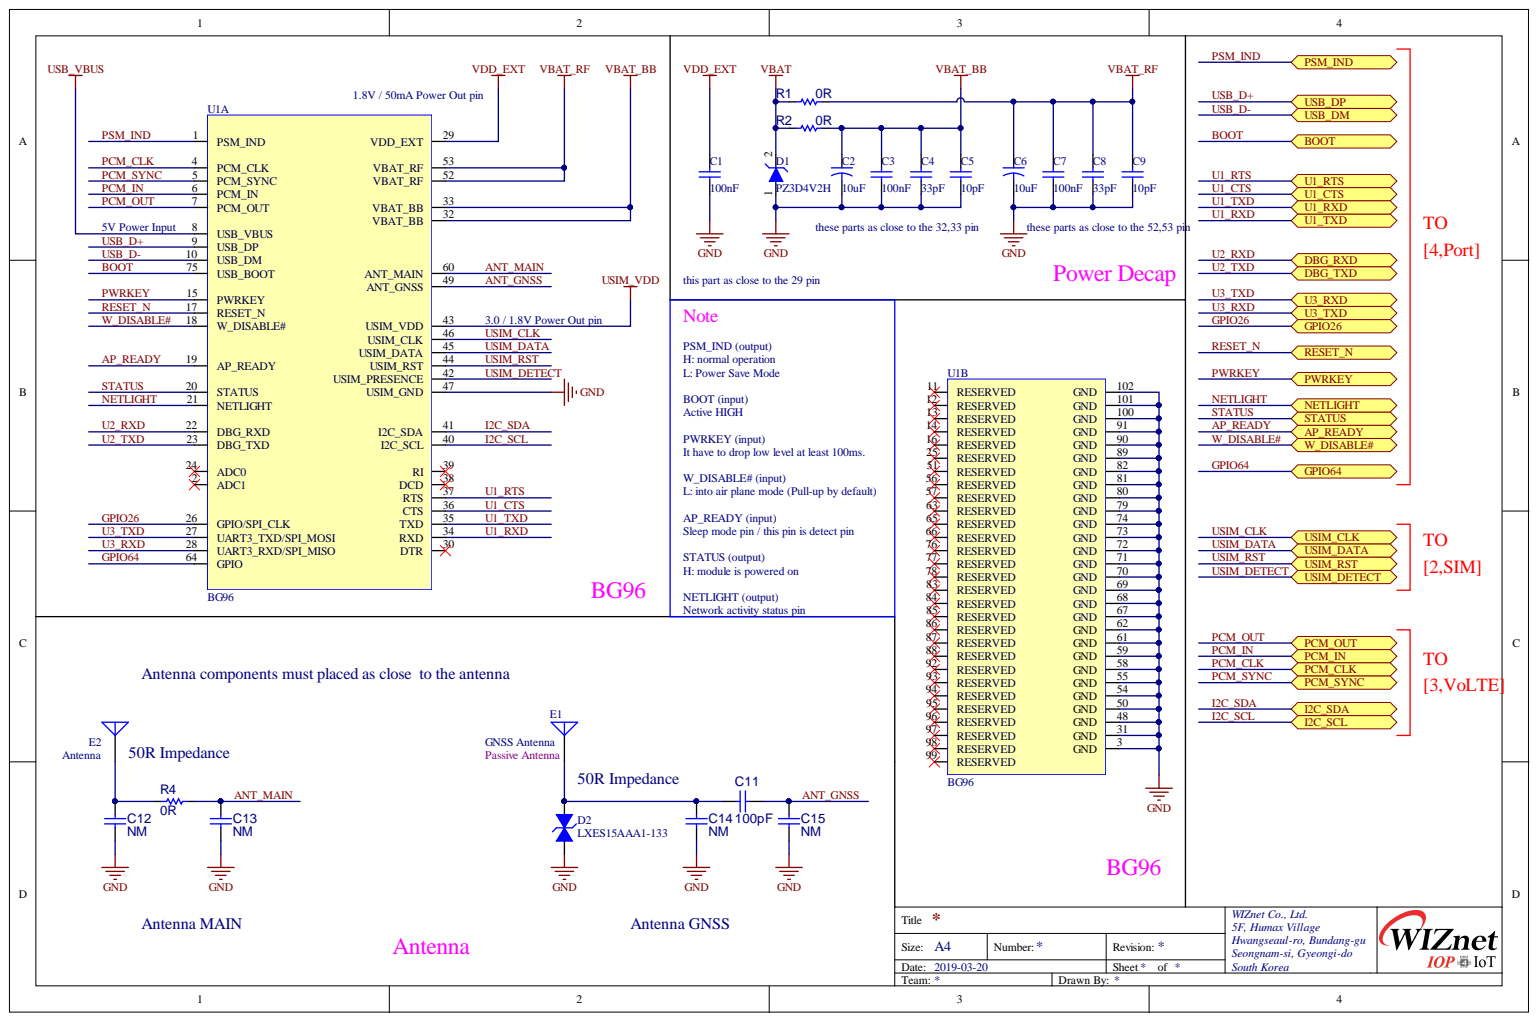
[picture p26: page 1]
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

A4 * S ize : | * Drawn Nu mb er: | * R e vi s ion :

Da t e : 9-03-20 | | S h * o f
Te m | By:

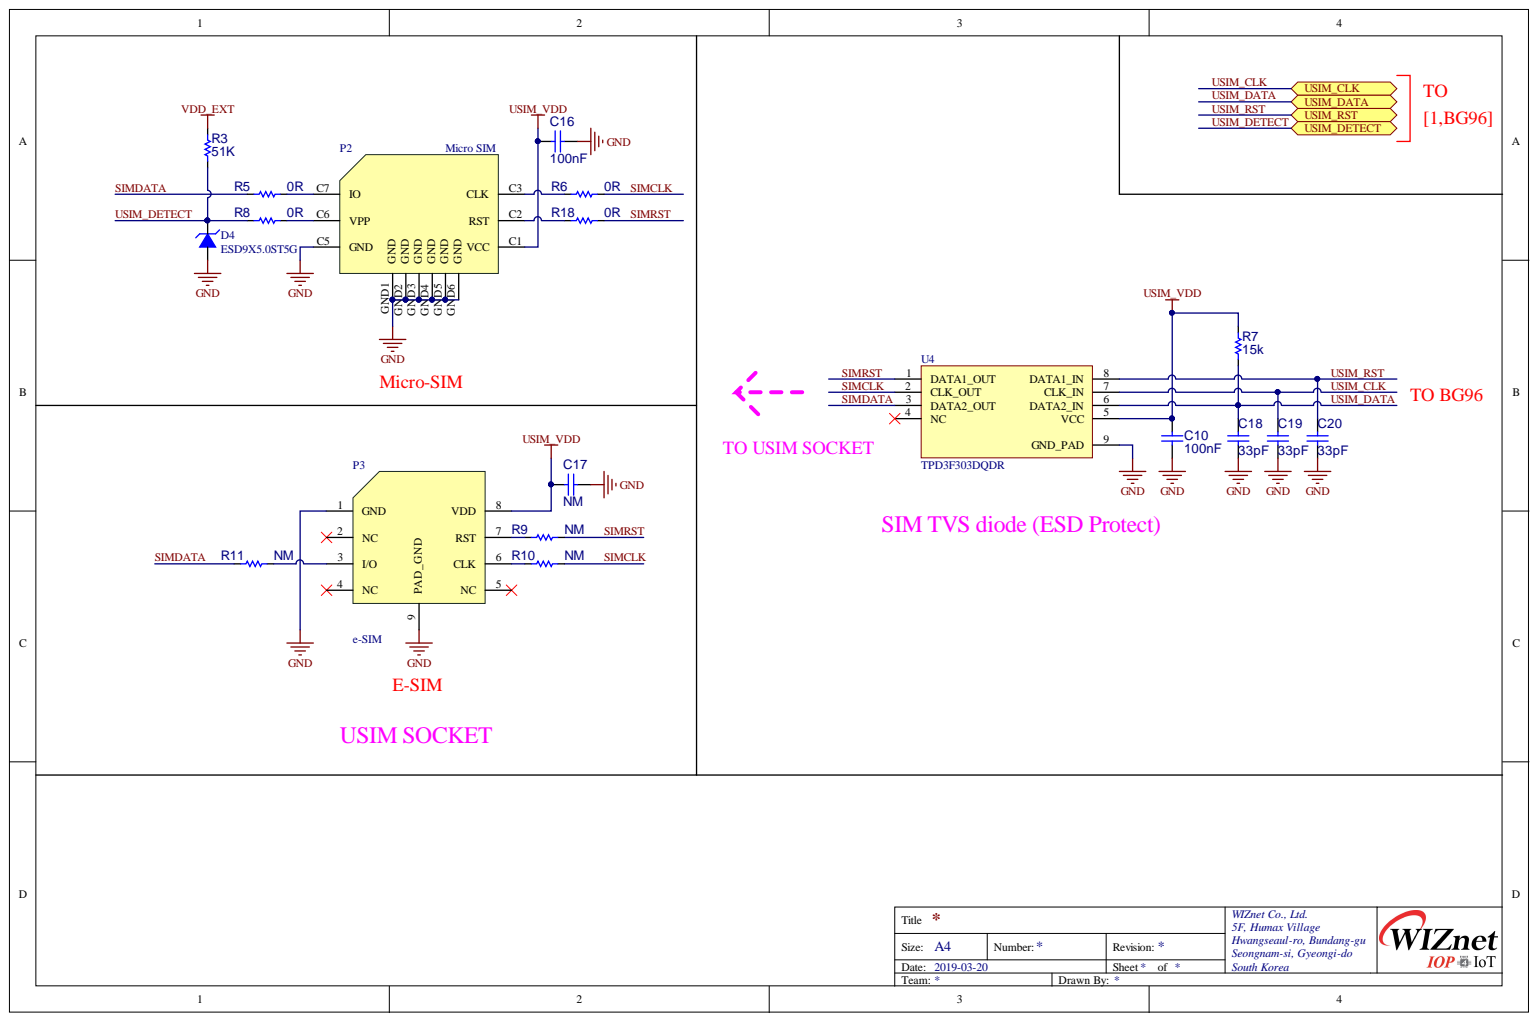
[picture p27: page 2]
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

A4 * S ize : | * Drawn Nu mb er: | * R e vi s ion :

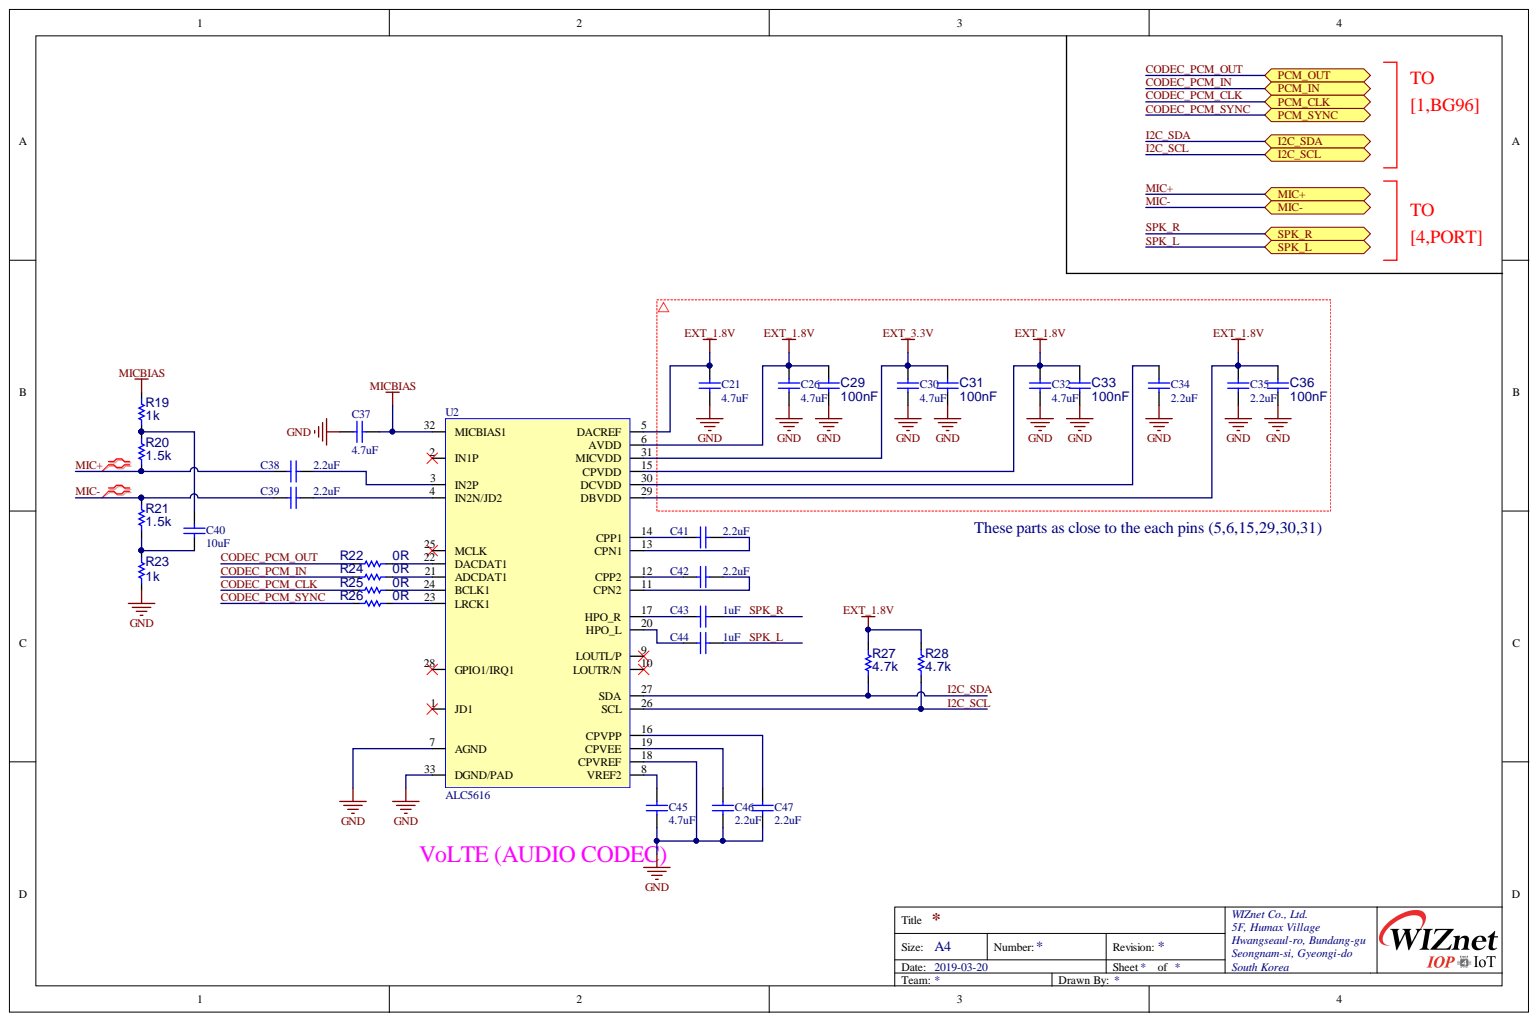
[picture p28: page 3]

These parts as close to the each pins (5,6,15,29,30,31)

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

A4 Size: | * Number: | * Revision:

Date: | | Sheet of *
Team: * | Drawn By: *

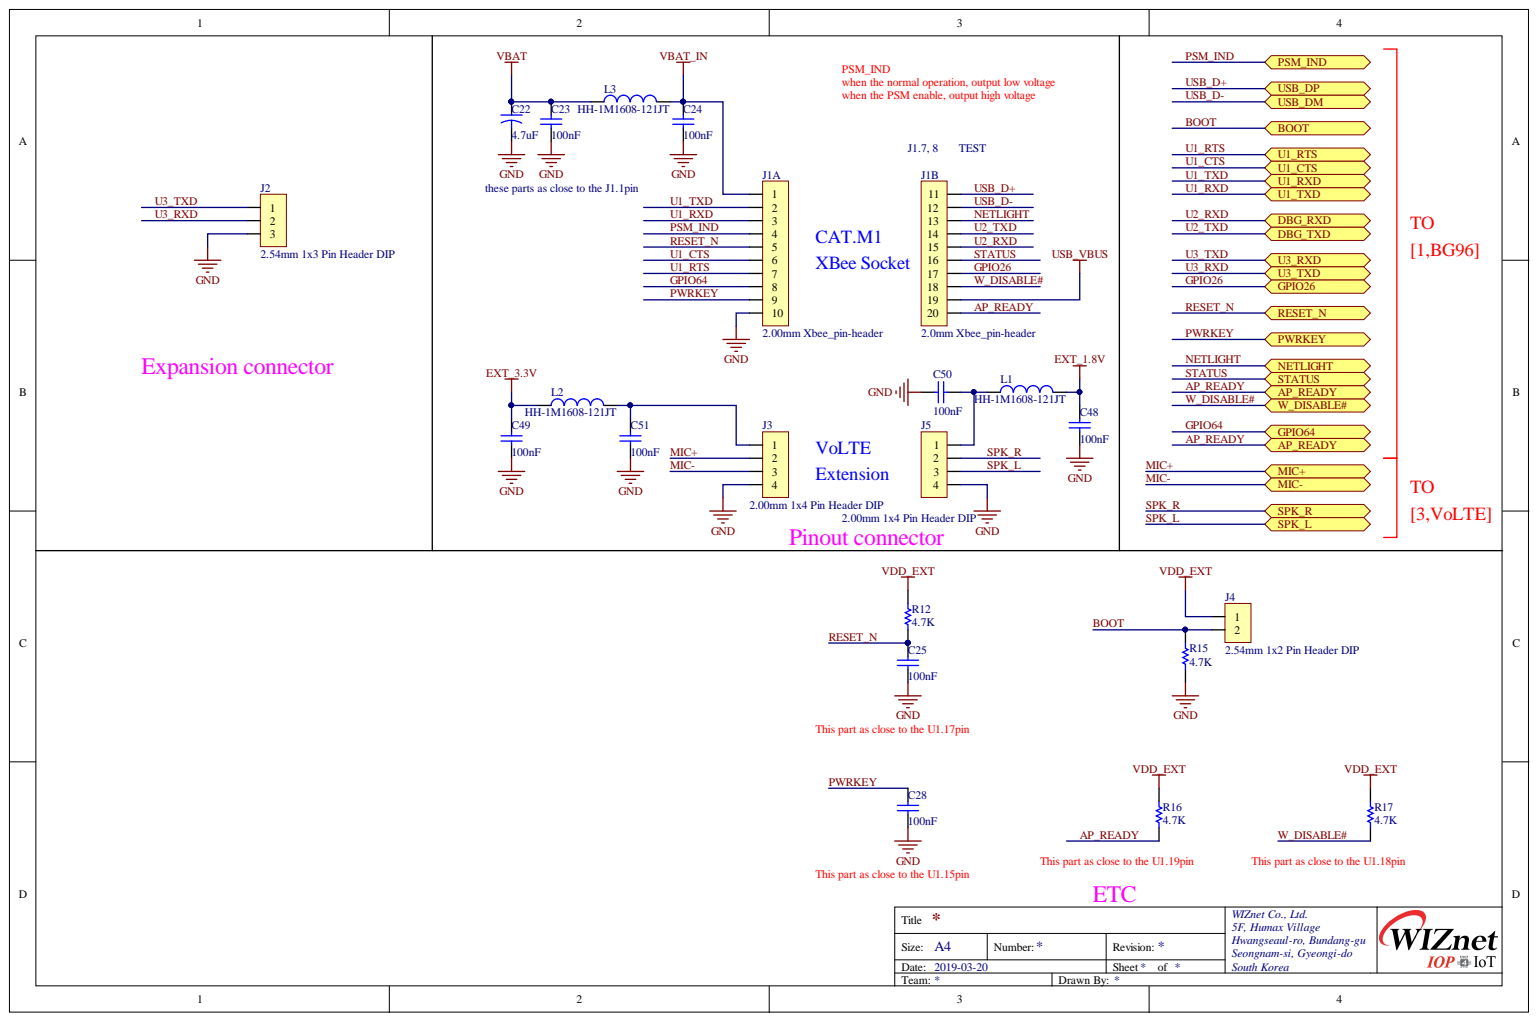
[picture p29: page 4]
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

A4 * S ize : | * Drawn Nu mb er: | * R e vi s ion :

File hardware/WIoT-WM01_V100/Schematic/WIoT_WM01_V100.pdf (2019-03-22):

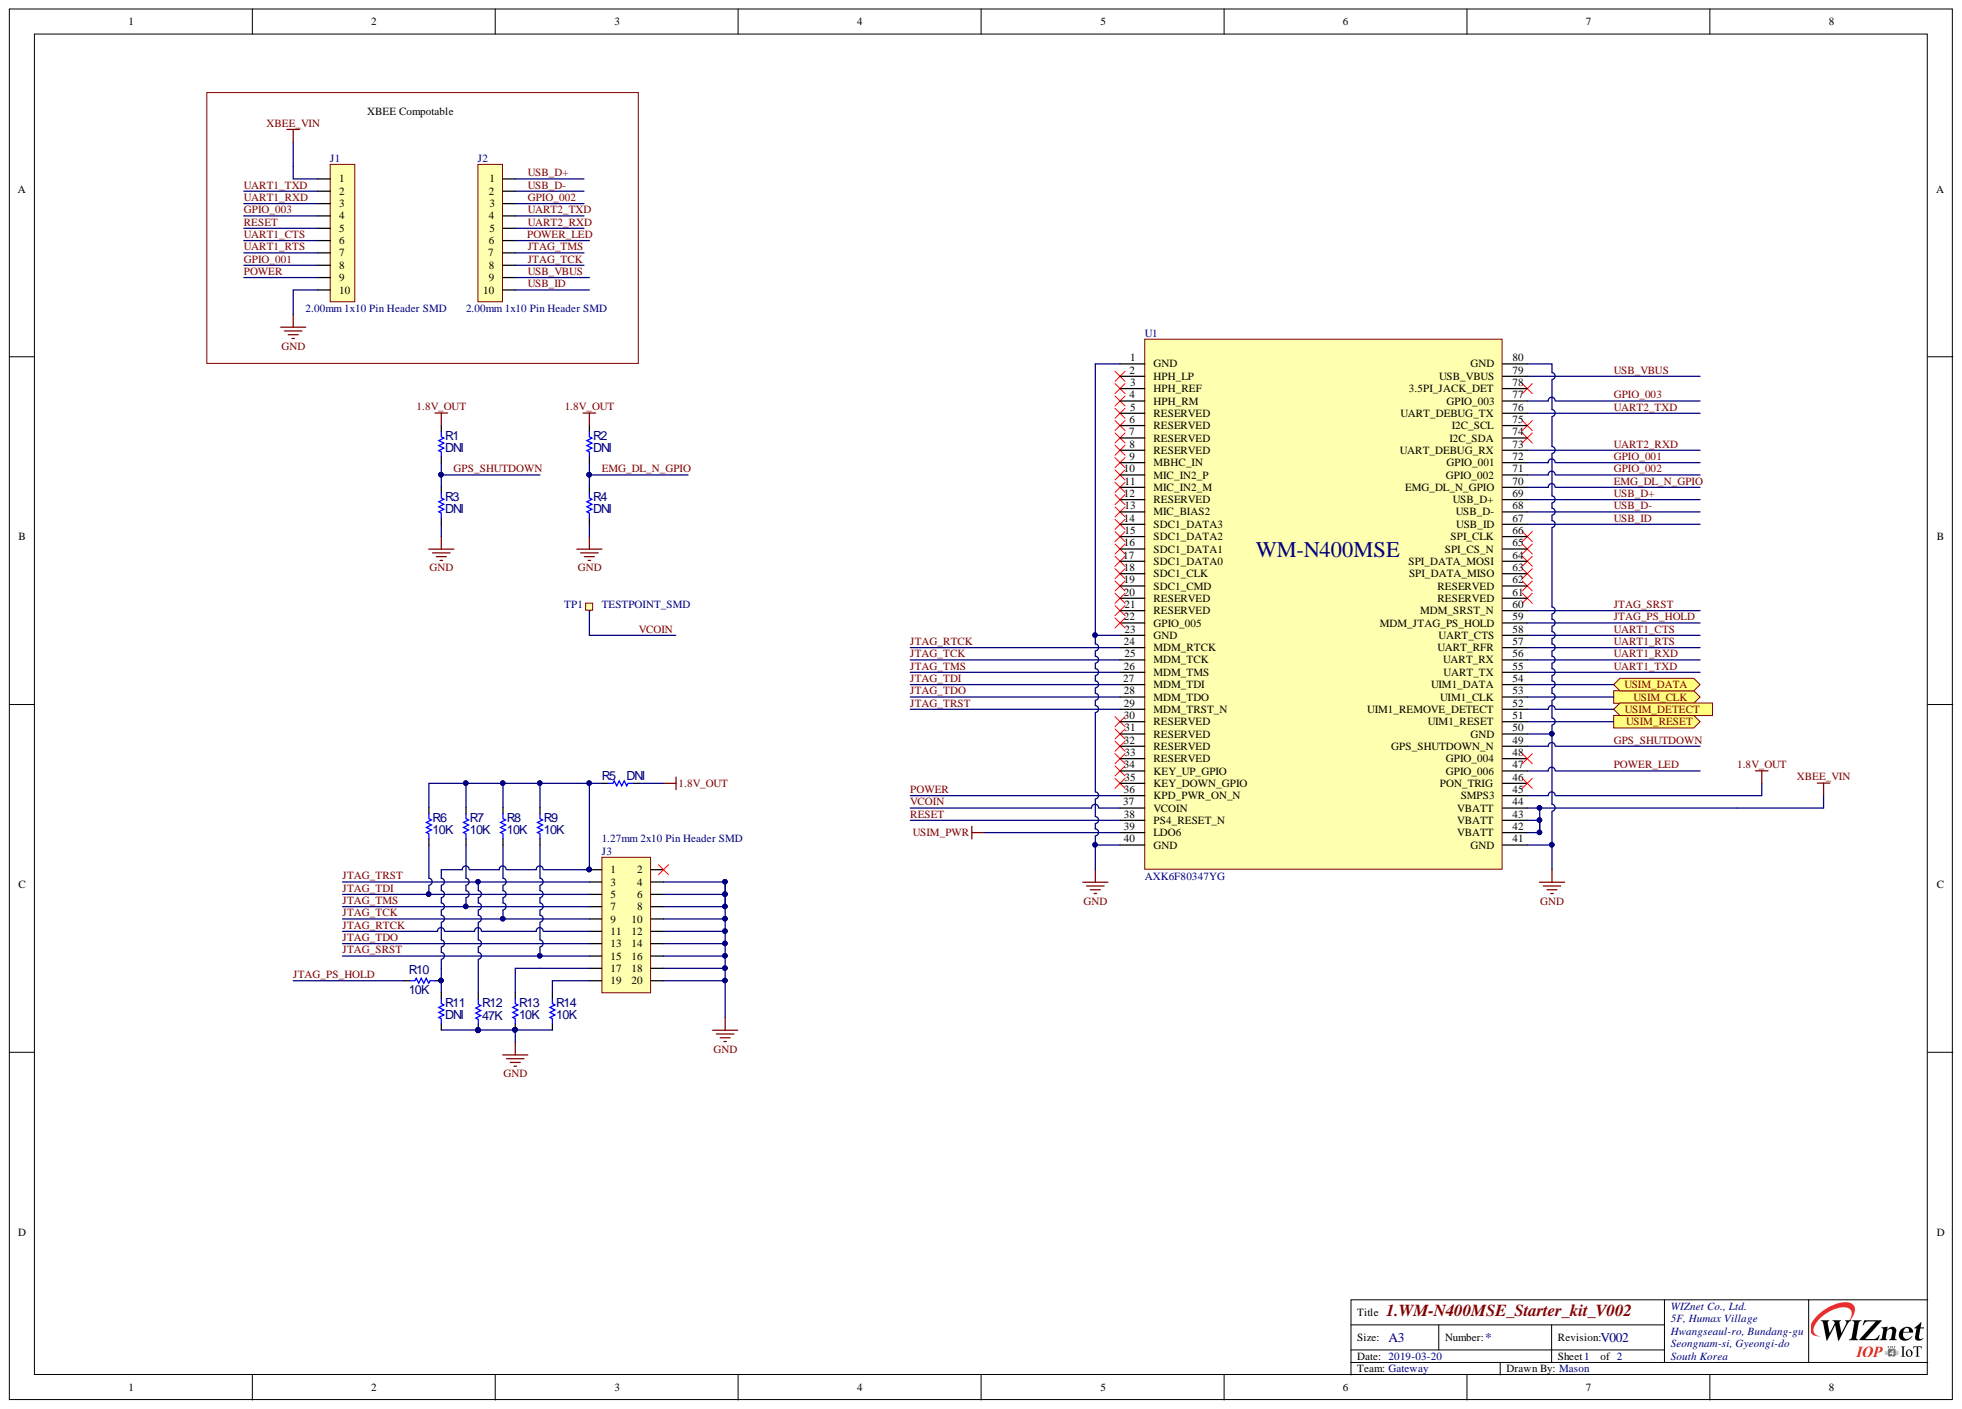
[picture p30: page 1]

4 3
4 2

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

Da t e : 2 0 1 9 -0 3 -2 0 | | S h e e t 1 o f 2
T e a m : Ga t e w a y | Dr a w n By : M a s o n

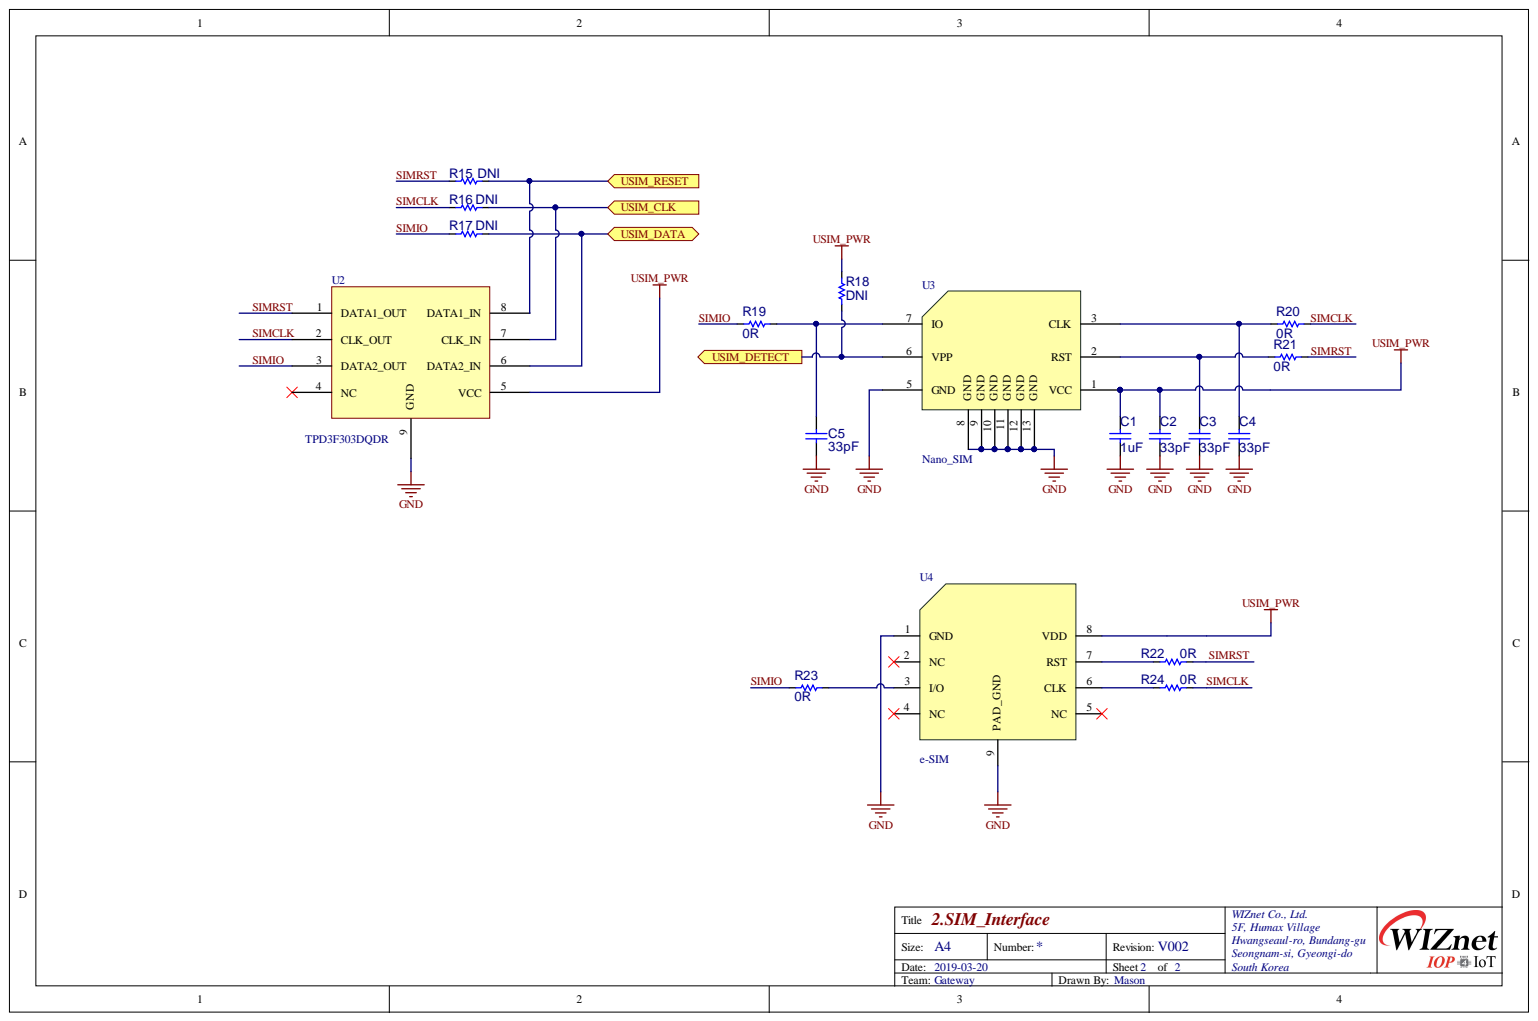
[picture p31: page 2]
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

A4 Size: | * Number: | V002 Revision:

Date: 2019-03-20 | | Sheet 2 of 2
Team: Gateway | Drawn By: Mason
